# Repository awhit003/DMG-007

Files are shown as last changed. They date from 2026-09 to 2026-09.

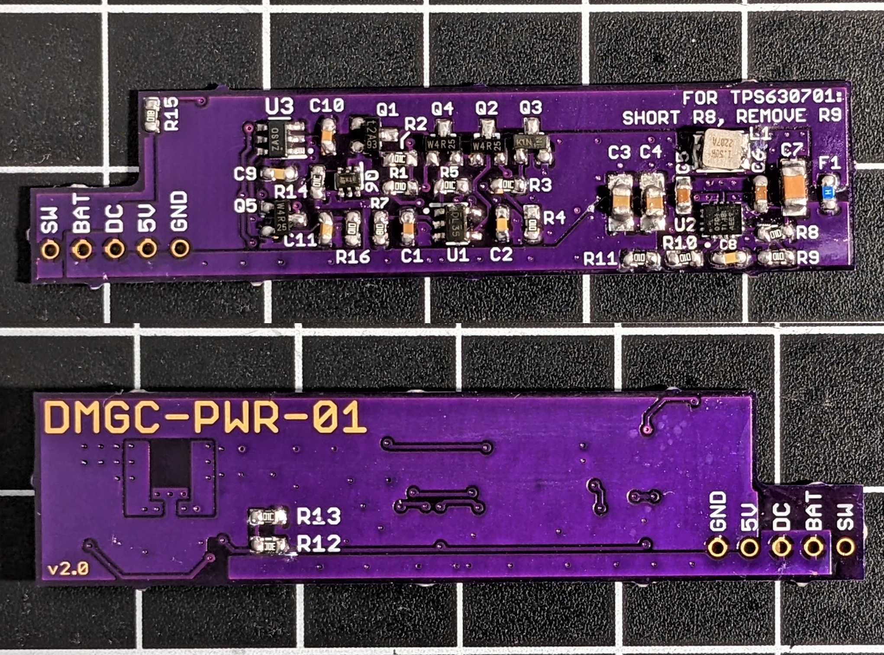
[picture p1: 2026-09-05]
hardware/boards/03-dmgc-pwr-01/DMGC-PWR-01_2-0_ASSEMBLED.png

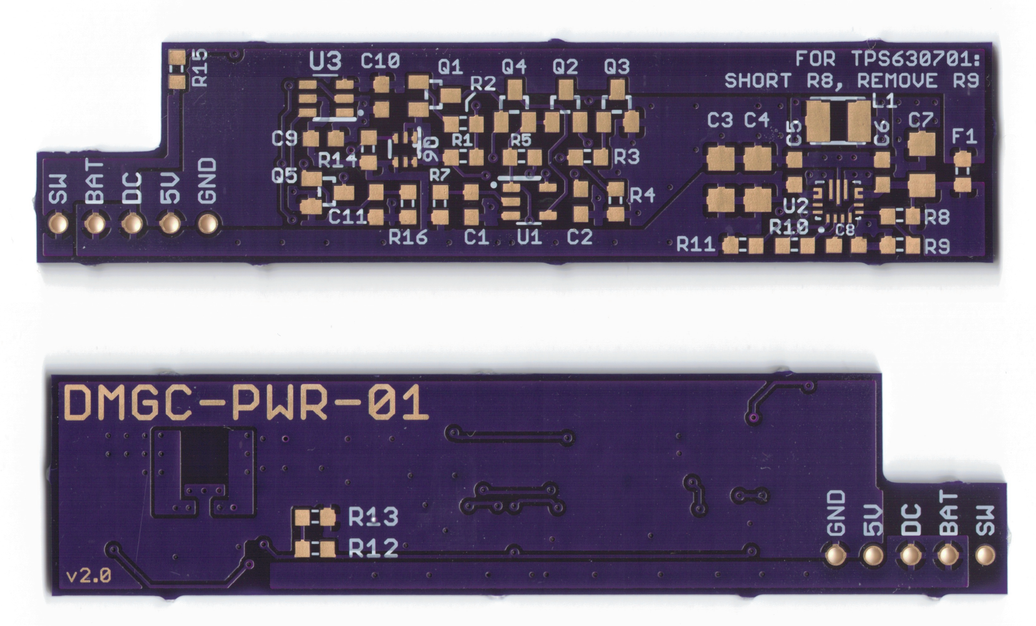
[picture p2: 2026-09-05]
hardware/boards/03-dmgc-pwr-01/DMGC-PWR-01_2-0.png

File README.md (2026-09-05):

# DMG-007

**DMG-007** is a modern hardware integration and re-engineering project for the original Nintendo Game Boy (DMG) form factor. 

The core philosophy of DMG-007 is **zero donor DMG-001 parts**: the console is built entirely from newly fabricated PCBs, modern off-the-shelf components, and automated surface-mount assembly. The **sole donor component** in the entire build is a salvaged **SGB-CPU** from a Japanese Super Famicom / Super Game Boy cartridge.

The designs and documentation are fabrication-agnostic and universally compatible with major PCB fabrication services including **OSH Park**, **PCBWay**, and **JLCPCB**.

---

## 🎯 Design Parameters & Architecture

1. **Zero DMG-001 Consoles Sacrificed:**
   - No original DMG-001 motherboards, power boards, audio boards, or screens are consumed.
   - The primary processor is an **SGB-CPU** (harvested from readily available Japanese Super Game Boy cartridges).
   - VRAM, work RAM, crystal oscillators, and audio amplification all use modern, commercially available replacement silicon and passives.

2. **Automated Surface-Mount (SMT) Assembly:**
   - Boards are designed with standard surface-mount packages (0805/0603 passives, standard IC packages) to allow automated pick-and-place assembly.
   - SGB-CPU (U1) and through-hole mechanical connectors (cartridge slot, headphone jack, battery contacts) are populated post-assembly.
   - Vendor-specific manufacturing instructions (e.g., JLCPCB/JLCONE tooling and LCSC part mappings) are maintained in dedicated vendor documentation.

3. **High-Performance Reflective Display (Sharp RLCD):**
   - Incorporates a modern ultra-fast 1-bit Reflective LCD panel (Sharp Memory LCD / RLCD `LS032B7DD02`, 3.2", 336×536).
   - Preserves the authentic, glare-free, outdoor-readable aesthetic of the original monochrome DMG without backlights or motion smear.
   - Driven by an on-board Raspberry Pi RP2040 utilizing clean-room PIO capture and 2×2 Bayer dithering.

4. **"God View" VRAM Bus Snooping (256×256 Viewport Expansion):**
   - The Sharp driver board includes a dedicated **24-pin 0.5mm FPC expansion port (`J4_VRAM_SNOOP`)**.
   - Snoops the Game Boy VRAM bus (`A0–A12`, `D0–D7`, `/WR`) via an optional parasitic flex cable.
   - Enables hardware capture of the entire internal 256×256 pixel background tilemap in real time, unlocking full-canvas wide-angle rendering beyond the clipped 160×144 PPU viewport.

5. **Clean Power Delivery:**
   - Dedicated high-efficiency synchronous buck-boost regulation (`DMGC-PWR-01`) delivering a rock-solid, isolated 5V rail capable of supporting the RLCD controller and modern audio amplifier across varying battery discharge curves.

---

## 🧩 Integrated Hardware Components & Attribution

This project brings together foundational designs created by talented open-source hardware developers across the retro-modding community:

| Module | Source Design | Original Author | Upstream License | Function in DMG-007 |
| :--- | :--- | :--- | :--- | :--- |
| **Motherboard** | [Super-DMG-01](https://github.com/kamicane/Super-DMG-01) | **kamicane** (Valerio Proietti) | CC BY-SA 4.0 | Main system logic board engineered to host the SGB-CPU, modern RAM, and USB-C power integration. |
| **Audio Board** | [Super DMG JACK](https://github.com/kamicane/Super-DMG-01) | **kamicane** (Valerio Proietti) | CC BY-SA 4.0 | Independent headphone and speaker audio board utilizing a PAM8302 mono Class-D amplifier. |
| **Power Supply** | [DMGC-PWR-01](https://github.com/MouseBiteLabs/Game-Boy-DMG-Color) | **MouseBiteLabs** (Bucket Mouse) | CC BY-SA 4.0 | High-efficiency buck-boost regulator board (TPS630702 based) with undervoltage latching. |
| **Display Subsystem**| Clean-Room Sharp RLCD Driver | DMG-007 Project | CC BY-SA 4.0 | RP2040 controller driving Sharp LS032B7DD02 with PIO capture, 2×2 Bayer dither, and 24-pin VRAM snooping bus. |

For detailed license terms and derivative compliance requirements, see [NOTICE.md](NOTICE.md) and [LICENSE](LICENSE).

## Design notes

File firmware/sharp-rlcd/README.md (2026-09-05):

# DMG-007 Sharp RLCD Driver Firmware

Clean-room open-source firmware for Raspberry Pi RP2040 driving the Sharp Memory LCD (LS032B7DD02) from Nintendo Game Boy DMG LCD signals.

## Architecture

* **PIO 0**: Samples Game Boy LCD `DATA0` and `DATA1` on `CL2` (pixel clock) falling edge.
  * Synchronized by `CL1` (horizontal line latch) and `VSYNC` (frame start).
* **DMA**: Transports line buffers to Core 1 without CPU intervention.
* **Core 1**: Converts 2-bit grayscale pixels (160x144) to 1-bit black & white (320x288) via 2x2 Bayer dithering matrix.
* **Core 0**: Handles USB interface, COM inversion periodic toggle (required for Sharp Memory LCD health), and system status.
* **SPI Controller**: Streams the 320x288 1-bit frame to the Sharp panel over high-speed serial bus at 60 Hz.

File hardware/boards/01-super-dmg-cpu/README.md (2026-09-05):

# Super DMG CPU

Super DMG CPU works with both IPS and DOT MATRIX LCD boards.

top bottom

## Credits

The schematic is largely based on [the work done by bit 9](https://imgur.com/a/X5qKI).

I used [Gekkio KiCAD libs](https://github.com/Gekkio/gekkio-kicad-libs) for a few symbols (cpu, ram, cart connector, link port). The specialized footprints were traced by me using fusion 360, using these [scans by bit 9](https://chipmusic.org/forums/topic/13608/dmg-main-board-schematic-circuit-arduinoboy/) as a reference.

## Warning

v1.8 and below have an error with the Link Port, where the footprint was flipped (sigh). If you have a v1.8 or below please don't use the link port, as it might damage the other Game Boy! This was fixed in later versions.

## Features

### Compatibility

Super DMG CPU can be built using new components, except for the CPU, power switch and link connector. It is also possible to use some components harvested from a DMG.

### USB Type-C

The round power connector is replaced with an USB Type-C port. The port is only connected to a pad on the motherboard, you need to add your own battery charger and/or power regulator if you want to make use of it. This port is optional.

### Power distribution IC

A power distribution IC takes the system load away from the power switch, so the game boy remains fully operational even if the switch is not in an optimal condition. This circuit can be bypassed with a jumper.

### Internal ProSound

The headphone output does not pass through the amplifier, only the volume potentiometer.

## BOM

| Designator | Package | Qty | Value / Description | Source |
|---|---|-----|---|---|
| U1 | QFP-80 14x20 p0.8 | 1 | CPU | DMG, SGB
| U2 | SOP-28 17.5x8.4 p1.27 | 1 | VRAM | DMG, SGB, [LCSC](https://lcsc.com/product-detail/C1351073.html)
| U3 | SOP-28 17.5x8.4 p1.27 | 1 | RAM | DMG, SGB, [LCSC](https://lcsc.com/product-detail/C1351073.html)
| U4 | SSOP-18 6x7.4 p0.8 | 1 | Audio Amplifier | DMG
| EXT1 | | 1 | Link Connector | DMG
| DA1, DA2, DA3, DA4 | SOT-23-3 | 4 | BAV99-7-F | [LCSC](https://www.lcsc.com/product-detail/C106919.html)
| C1, C23 | 3528 | 2 | 100µf tantalum | [LCSC](https://lcsc.com/product-detail/C122271.html)
| SW1 | | 1 | Power Switch | DMG
| U5 | SOT-23-5 | 1 | Power Distribution | [LCSC](https://lcsc.com/product-detail/C517266.html)
| D2 | SOD-123 | 1 | 1N414 | [LCSC](https://lcsc.com/product-detail/C83528.html)
| X1 | HC-49S | 1 | 4.194304 MHz | DMG, [LCSC (TH)](https://lcsc.com/product-detail/C718646.html), [LCSC (SMD)](https://lcsc.com/product-detail/C2149317.html)
| USB1 | USB_C_16p | 1 | Charge Connector | [LCSC](https://lcsc.com/product-detail/C2931472.html)
| VR1 | | 1 | Volume Pot | DMG, [AliExpress](https://www.aliexpress.com/item/32840044311.html)
| CN1 | 1.25 x 21 SMD | 1 | LCD Board Connector | DMG, [AliExpress](https://www.aliexpress.com/item/1005005484837763.html)
| CN2 |  | 1 | Cart Connector | DMG, [AliExpress](https://www.aliexpress.com/item/1005002719771295.html)
| CN3 | | 1 | AA Battery Contacts | DMG, [AliExpress](https://www.aliexpress.com/item/32801068366.html)
| CN4 | 1.25 TH | 1 | Lipo Battery Connector | [LCSC](https://www.lcsc.com/product-detail/C722595.html)
| C3, C4 | 0805 | 2 | 1µF |
| C5, C6 | 0805 | 2 | 10µF |
| C7, C8, C9 | 0805 | 3 | 47nF |
| C10, C24, C25 | 0805 | 3 | 100nF |
| C12, C13, C14 | 0805 | 3 | 10nF |
| C16, C17, C18, C19 | 0805| 4 | 100pF |
| C21, C22 | 0805 | 2 | 27pF |
| R1, R2, R3, R4 | 0805 | 4 | 220Ω|
| R5, R6 | 0805 | 2 | 510Ω |
| R7 | 0805 | 1 | 180kΩ |
| R8 | 0805 | 1 | 1MΩ |
| R9 | 0805 | 1 | 10kΩ |
| R10, R11 | 0805 | 2 | 5.1kΩ |

## Assembly

- Solder all SMD components on the front side
- If using a power board with integrated power distribution close ```J5``` and do not install ```U5```, ```C24```, ```C25```, ```R9```
- If using an external amplifier, such as [Super DMG JACK](../super-dmg-jack) do not install ```U4```, ```C5-C9```, ```C23```
- If you do not need link functionality you can omit ```EXT1```, ```DA1-DA4```, ```R1-R4```, ```C16-C19```, ```D2```
- Solder the through hole components and the LCD board connector
- (Optional) solder the usb connector and cut an opening for the usb port in the front shell using the provided [rudimentary jig](../3d_models/dmg_usbc_jig.stl)
- The original DC jack hole can be covered with this simple [3d printed plug](../3d_models/dmg_dc_plug.stl)

## Notes

If using an original LCD board you need an original *DMG DC CONV* voltage regulator, as acceptable modern replacements that also include the -18v rail *do not exist yet*.

This pcb cannot be easily biverted yet.

## Ordering

[pcbway](https://www.pcbway.com/QuickOrderOnline.aspx?projectid=13266&issmt=0)
[pcbway](https://pcbway.com/g/Gw03Yt)

Make sure you order with 1.0mm thickness.

## License

This work is licensed under the [Creative Commons Attribution-ShareAlike 4.0 International License.](http://creativecommons.org/licenses/by-sa/4.0/)

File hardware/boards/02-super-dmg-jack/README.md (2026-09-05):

# Super DMG JACK

Super DMG JACK is a replacement headphone/audio PCB for the original Game Boy. It can be used on a stock DMG or the Super DMG-01.

It uses a PAM8302 mono amplifier to power the speaker when no headphones are present, but it can also be built as a headphone jack replacement using the amplifier on the CPU board.

The amplifier schematic is based on [Adafruit's pam8302 amplifier PCB](https://github.com/adafruit/Adafruit-PAM8302-Mono-Amplifier-PCB).

The headphone output needs to be unamplified, and grabbed _after_ the DMG volume potentiometer.

sdmg jack top sdmg jack bottom

sdmg jack sdmg jack full

## BOM

| Designator | Package | Qty | Value / Description | Source |
|---|---|-----|---|---|
| CN1 | PJ-3043-B | 1 | Headphone connector | [LCSC](https://lcsc.com/product-detail/C2682182.html) |
| CN2 | 1.25 TH | 1 | CPU PCB Connector | [LCSC](https://lcsc.com/product-detail/C722595.html) |
| CN3 | 1.25 TH | 1 | Speaker Connector | [LCSC](https://lcsc.com/product-detail/C722604.html) |
| U1 | SOP-8 | 1 | PAM8302 | [LCSC](https://lcsc.com/product-detail/C112137.html) |
| U2 | SOT-23-5 | 1 | SN74AHC1G14 | [LCSC](https://lcsc.com/product-detail/C7469.html) |
| VR1 | Bourns TC33X-2-103E | 1 | 10kΩ SMD | [LCSC](https://lcsc.com/product-detail/C719176.html) |
| FB1, FB2 | 0805 | 2 | Ferrite Bead ||
| C1, C2, C5 | 0805 | 3 | 1µf ||
| C3, C4 | 0805 | 3 | 220pf ||
| R1, R2 | 0805 | 2 | 220Ω ||
| R3, R4 | 0805 | 2 | 100Ω ||
| R5 | 0805 | 1 | 10kΩ ||

I got premade wires from [AliExpress](https://www.aliexpress.com/item/1005002353691025.html) (1.25mm 2p and 5p), but you can also just use 28/30 awg without connectors.

I use "WSC" 8Ω 2W speakers from AliExpress.

## DMG Pinout

dmg-pinout

## Full Installation

Important: do not solder ```U2``` and/or do not wire the (E)nable signal. The speaker must be connected to this board.

- Solder the SMD components
- Solder the through hole components
- On the stock DMG solder the L/R signals to the volume potentiometer (** after pot), on Super DMG-01 solder to the bottom pads directly
- Get power from the 5v rail on the CPU board
- Adjust the trimpot

### Trimpot notes

Adjust the trimpot to reduce the power draw and max volume of the amplifier. Boot the DMG at minimum volume, and slowly turn it up, while also adjusting the trimpot. The Game Boy will shut down if you're drawing too much power.
Do the final trimpot adjustment once the DMG volume is at its maximum value.

The final maximum volume will depend on the batteries and the voltage regulator you're using.

## Jack-only Installation

The jack-only installation is meant to be used with the on-board DMG amplifier, however you still need to solder an extra wire for power as the ENABLE signal needs to be inverted.

Important: solder only ```U2```, ```R5```, the headphone jack and the CPU PCB connector. The speaker must be kept in the LCD board.

- Solder the SMD components
- Solder the through hole components
- On the stock DMG solder the L/R signals to the volume potentiometer (** after pot), on Super DMG-01 solder to the bottom pads directly
- Get power from 5V (Super DMG CPU) or SW (stock DMG) on the CPU board

## Notes

3d print the [jack spacer](../3d_models/super_dmg_jack_spacer.stl) for correct alignment.

## Ordering

[pcbway](https://www.pcbway.com/QuickOrderOnline.aspx?projectid=13350&issmt=0)
[pcbway](https://pcbway.com/g/Gw03Yt)

Make sure you order in 1.0mm thickness.

## License

This work is licensed under the [Creative Commons Attribution-ShareAlike 4.0 International License.](http://creativecommons.org/licenses/by-sa/4.0/)

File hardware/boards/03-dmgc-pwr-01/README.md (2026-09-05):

# DMGC-PWR-01

DMGC-PWR-01_2-0_black
DMGC-PWR-01_2-0_ASSEMBLED_black

*Note: This image shows v2.0. There is minimal difference between this and v2.3.*

The PWR board has gone through a few iterations. Because the system will run with 4x AA batteries or the DC jack input, the range of input voltages is relatively wide - anywhere between ~4 V up to ~8 V, plus margin. The output voltage must be maintained at 5 V. The logical choice would be a buck-boost converter. Thus, the DMGC-PWR-01 utilizes the TPS630702 (or TPS63070 or TPS630701) – a buck-boost converter with only a few external parts required for operation, that accepts anywhere between 2 V and 16 V to produce a 5 V output.

This board is likely the most complex part of the build. I spent a lot of time tuning the circuit to produce the exact results I wanted with ample protection downstream of the converters.

For a technical explanation of the CPU board, please view the README in the Technical folder.

## Board Characteristics
The zipped folder contains all the gerber files for this board.
-	Layers: 2
-	Thickness: 1.2 mm or smaller
-	Surface Finish: ENIG or HASL

*HASL is acceptable, but might introduce a bit of difficulty soldering the QFN chip owing to the possibly uneven surface compared to an ENIG finish.*

<a href="https://www.etsy.com/listing/1317694018/game-boy-dmgc-pwr-board">**I sell this board on Etsy, so you don't have to buy multiples from board fabricators.**</a>

You can alternatively use the zipped folder at any board fabricator you like. You may also buy the board from PCBWay using this link (disclosure: I receive 10% of the sale value to go towards future PCB orders):

<a href="https://www.pcbway.com/project/shareproject/Game_Boy_DMG_Color_DMGC_PWR_01_f8f2e84a.html">PCB from PCBWay</a>

## Configuring for Different TPS chips on U2

For TPS63070 or TPS630702, R8 needs to be 523k and R9 needs to be 100k, as indicated in the BOM.

For TPS630701, you need to short R8 with a solder bridge/wire or a zero ohm resistor, and remove R9 completely.

**It is critical you configure the board correctly, otherwise you may damage your system.**

## Using in an Original DMG (UNTESTED!)

This board can (probably) be used as a replacement to the original DMG power board, provided you are using an IPS screen that only requires a 5 V output. This board will not supply voltages for the LCD, so it cannot be used in an unmodded DMG.



Follow the silkscreen on the back of the board to connect wires to the DMG motherboard, as shown below (image from Gekkio's Game Boy Hardware Database: https://gbhwdb.gekkio.fi/consoles/dmg/). The red wire on the main DMG CPU board indicates pin 1. The blue box on the back of the DMG CPU board indicates the connection for the BAT hole.



IF you happen to test this (at your own risk!) let me know your results.

## Bill of Materials

Here, I have provided links to components I used personally (or suitable replacements). This BOM is also included in Excel format in the root folder.

| Reference Designators | Qty | Value/Part Number | Package | Description | Comment | Source |
| --- | --- | --- | --- | --- | --- | --- |
| C1, C5, C6 | 3 | 10uF | 0603 | Capacitor (MLCC) | Should be X5R (or better), at least 16V | [https://www.mouser.com/ProductDetail/Murata-Electronics/GRM188R61E106KA73J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](https://www.mouser.com/ProductDetail/Murata-Electronics/GRM188R61E106KA73J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) |
| C3, C4 | 2 | 22uF | 1206 | Capacitor (MLCC) | Should be X5R (or better), at least 16V | [https://www.mouser.com/ProductDetail/Samsung-Electro-Mechanics/CL31A226KAHNNNE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](https://www.mouser.com/ProductDetail/Samsung-Electro-Mechanics/CL31A226KAHNNNE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) |
| C7 | 1 | 47uF | 1206 | Capacitor (MLCC) | Should be X5R (or better), at least 16V | [https://www.mouser.com/ProductDetail/Murata-Electronics/GRM31CR61C476ME44K?qs=QzBtWTOodeVeYV6UhCOqow%3D%3D](https://www.mouser.com/ProductDetail/Murata-Electronics/GRM31CR61C476ME44K?qs=QzBtWTOodeVeYV6UhCOqow%3D%3D) |
| C8, C9, C11 | 3 | 0.1uF | 0603 | Capacitor (MLCC) | | [https://www.mouser.com/ProductDetail/?qs=l5k%252BbMnNDknCtKnMv1oEgA%3D%3D](https://www.mouser.com/ProductDetail/?qs=l5k%252BbMnNDknCtKnMv1oEgA%3D%3D) |
| C10 | 1 | 0.01uF | 0603 | Capacitor (MLCC) | | [https://www.mouser.com/ProductDetail/KEMET/C0603C103J5RACTU?qs=BimOss5pjlFJEfKhlb7g1g%3D%3D](https://www.mouser.com/ProductDetail/KEMET/C0603C103J5RACTU?qs=BimOss5pjlFJEfKhlb7g1g%3D%3D) |
| F1 | 1 | 1A | 0603 | Fuse | | [https://www.mouser.com/ProductDetail/Vishay-Beyschlag/MFU0603FF01000P100?qs=oI046glRurtlP8n%252B3l7CPg%3D%3D](https://www.mouser.com/ProductDetail/Vishay-Beyschlag/MFU0603FF01000P100?qs=oI046glRurtlP8n%252B3l7CPg%3D%3D) |
| L1 | 1 | 1.5uH | 1212 | Inductor | Saturation current should be at least 2A | [https://www.mouser.com/ProductDetail/70-IHLP1212BZER1R5M1](https://www.mouser.com/ProductDetail/70-IHLP1212BZER1R5M1) |
| Q1 | 1 | MMBT3906 | SOT23 | PNP BJT | | [https://www.mouser.com/ProductDetail/Micro-Commercial-Components-MCC/MMBT3906HE3-TP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](https://www.mouser.com/ProductDetail/Micro-Commercial-Components-MCC/MMBT3906HE3-TP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) |
| Q2, Q4, Q5 | 3 | 2N7002 | SOT23 | N-channel MOSFET | | [https://www.mouser.com/ProductDetail/Nexperia/2N7002NXBKR?qs=%252B6g0mu59x7J2ddJstTJGkQ%3D%3D](https://www.mouser.com/ProductDetail/Nexperia/2N7002NXBKR?qs=%252B6g0mu59x7J2ddJstTJGkQ%3D%3D) |
| Q3 | 1 | MMBT3904 | SOT23 | NPN BJT | | [https://www.mouser.com/ProductDetail/Nexperia/MMBT3904VL?qs=cnAQGvEIVkKbCwIpHJoHxQ%3D%3D](https://www.mouser.com/ProductDetail/Nexperia/MMBT3904VL?qs=cnAQGvEIVkKbCwIpHJoHxQ%3D%3D) |
| Q6 | 1 | SI1443EDH | SOT363 | P-channel MOSFET | | [https://www.mouser.com/ProductDetail/Vishay-Semiconductors/SI1443EDH-T1-GE3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](https://www.mouser.com/ProductDetail/Vishay-Semiconductors/SI1443EDH-T1-GE3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) |
| R1, R4, R7, R9, R10, R11, R16 | 7 | 100k | 0603 | Resistor | R9 should have at least 1% tolerance | [https://www.mouser.com/ProductDetail/YAGEO/RC0603FR-07100KL?qs=e1ok2LiJcmaihem8Va5%2Fsw%3D%3D](https://www.mouser.com/ProductDetail/YAGEO/RC0603FR-07100KL?qs=e1ok2LiJcmaihem8Va5%2Fsw%3D%3D) |
| R2, R3, R5, R13, R14 | 5 | 10k | 0603 | Resistor | | [https://www.mouser.com/ProductDetail/YAGEO/RC0603FR-0710KL?qs=grNVn54RoB%252B3GtjbJj3wJQ%3D%3D](https://www.mouser.com/ProductDetail/YAGEO/RC0603FR-0710KL?qs=grNVn54RoB%252B3GtjbJj3wJQ%3D%3D) |
| R15 | 1 | 1k | 0603 | Resistor | | [https://www.mouser.com/ProductDetail/YAGEO/RC0603FR-071KL?qs=VU8sRB4EgwApHsk4rF%2F3zg%3D%3D](https://www.mouser.com/ProductDetail/YAGEO/RC0603FR-071KL?qs=VU8sRB4EgwApHsk4rF%2F3zg%3D%3D) |
| R8 | 1 | 523k | 0603 | Resistor | At least 1% tolerance. Not needed if using TPS630701 | [https://www.mouser.com/ProductDetail/YAGEO/RC0603FR-07523KL?qs=TkC2zyCLazpzUFWuXe7EHg%3D%3D](https://www.mouser.com/ProductDetail/YAGEO/RC0603FR-07523KL?qs=TkC2zyCLazpzUFWuXe7EHg%3D%3D) |
| R12 | 1 | 20k | 0603 | Resistor | | [https://www.mouser.com/ProductDetail/YAGEO/RC0603FR-0720KL?qs=VU8sRB4EgwCsxfrjtEIKPQ%3D%3D](https://www.mouser.com/ProductDetail/YAGEO/RC0603FR-0720KL?qs=VU8sRB4EgwCsxfrjtEIKPQ%3D%3D) |
| U1 | 1 | TPS3840DL35 | SOT23-5 | Supervisory IC | Could feasibly use TPS3840DL32 if 35 is out of stock | [https://www.mouser.com/ProductDetail/Texas-Instruments/TPS3840DL35DBVR?qs=7MVldsJ5UawbjRj7dP73rA%3D%3D](https://www.mouser.com/ProductDetail/Texas-Instruments/TPS3840DL35DBVR?qs=7MVldsJ5UawbjRj7dP73rA%3D%3D) |
| U2 | 1 | TPS63070, TPS630701, TPS630702 | 15-VQFN-HR | Buck-boost converter | Might be difficult to find. TPS630702 preferred, but all will work. Check https://octopart.com/search?q=tps63070&currency=USD&specs=0 | [https://www.mouser.com/ProductDetail/Texas-Instruments/TPS630702RNMT?qs=vLWxofP3U2wR9GhA3fXurw%3D%3D](https://www.mouser.com/ProductDetail/Texas-Instruments/TPS630702RNMT?qs=vLWxofP3U2wR9GhA3fXurw%3D%3D) |
| U3 | 1 | TPS3702CX50 | SOT23-6 | Supervisory IC | Optional IF you fully test the power board and confirm proper 5V operation | [https://www.mouser.com/ProductDetail/595-TPS3702CX50DDCR](https://www.mouser.com/ProductDetail/595-TPS3702CX50DDCR) |

## Revision History

### v2.3
- Moved some components
- Removed C2 (not needed on previous revisions either)
- Fixed DMG connection silkscreen
- Changed RC time constant for undervoltage detection
- Added test points across the board

### v2.2
- Added F1 back
- Added DMG connections notation on silkscreen

### v2.1
- Moved R12/R13 to front of the board
- Removed F1

### v2.0 (for sale)
- Release version

## License
<br />This work is licensed under a <a rel="license" href="http://creativecommons.org/licenses/by-sa/4.0/">Creative Commons Attribution-ShareAlike 4.0 International License</a>. You are able to copy and redistribute the material in any medium or format, as well as remix, transform, or build upon the material for any purpose (even commercial) - but you **must** give appropriate credit, provide a link to the license, and indicate if any changes were made.

©MouseBiteLabs 2022

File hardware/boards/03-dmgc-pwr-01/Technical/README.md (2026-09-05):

# Technical Design Document

This write-up serves as a technical explainer for the DMGC-PWR-01. This board is the powerhouse of the cell.

## Schematic and CPU Board Interfacing

There are five wires that connect to the CPU board power supply circuitry. Pin 1 is the GND reference and pin 2 is the 5 V output from the PWR board. Pin 4, VCC, is the input voltage, which is always powered from the CPU board. SW is the output of half the power switch on the CPU board - connected to VCC when on, floating when off (ultimately tied to GND through R16 on the PWR board). On the CPU board, pin 3 is connected to the DC jack output, but on this board I connect this to VCC as well, so that either batteries or the DC jack will power this board. A different revision might utilize the DC jack for something else, such as charging a LiPo battery, which is why I left these pins separate.



The battery voltage, VCC, is applied to the buck-boost input voltage pin, without routing through the power switch on the CPU. Instead, the power switch controls the buck-boost converter’s enable pin through a load switch circuit.

## Buck-Boost Converter (U2)

U2 can be TPS63070, TPS630701, or TPS630702. TPS630701 is a fixed 5 V buck-boost, while the other two have adjustable output via a voltage divider. The only difference between TPS63070 and TPS630702 is that the latter has an output discharge function - when the output is disabled, a low impedance (~200 Ω) is connected to the rail internally to quickly discharge the output capacitors. If you have a choice, I would recommend using the TPS630702 over the other two, and the TPS630701 over the TPS63070 just because it's a bit more convenient (and foolproof) to use the fixed output version of the chip. But any three of them will work perfectly fine.

The bottom third of the schematic is the entire buck-boost stage. I followed the TPS63070 datasheet for choosing values of the input and output capacitance, the inductor, and the feedback resistors. R8 and R9 set up a voltage divider for setting the output of the adjustable TPS630702 or TPS63070 – if the TPS630701 is used instead, which is the 5 V fixed output version, then R8 should be short circuited and R9 can be removed. **If you leave R8 and R9 at the values they are with the fixed 5 V chip, the output will shoot up to ~11V. I strongly recommend testing this power supply board separately from the rest of the system to ensure the 5 V output is correct and steady, without frying anything else downstream.**

The buck-boost chip is activated when the EN pin is higher than 800 mV (there is an internal ~70 microsecond delay before activation after this voltage is reached). This pin is controlled by the PSU_EN net, which is influenced by two chips – U3 (overvoltage protection) and U1 (undervoltage detection). If no errors are detected in the power supply, then PSU_EN will pull up to VCC_LATCH and activate U2. If either an overvoltage on the 5 V line or an undervoltage on the battery supply is detected, the PSU_EN net is pulled to GND and latched off until the power switch is cycled. R5, R12, and R13 set up voltage dividers that ensure if the EN pin passes 800 mV, the gate-source voltage on Q2 will be at least 2.4 V, meaning the latching circuit will be set up before the 5 V supply is generated (VGSth of Q2 is ~2.1 V, max). R13 also ensures the EN pin is pulled to GND when the power switch is turned off. Detailed operation on the PSU_EN net can be found below. 

F1 is a 1 A fuse on the 5 V output, which in hindsight is probably overkill, since the CPU board has protections that will likely always trip first (the 1 A PTC specifically). When testing the PWR board, I shorted the 5 V supply to GND to see if the fuse would pop, and the PTC opened up first every time I tried. But, I have plenty of 1 A fuses lying around, so there’s little reason not to include it just in case, since the TPS63070 chips can output up to 3.6 A. A fuse could prevent a feed-the-fault type of error, however rare that scenario likely is.

## Overvoltage Protection (U3)

Onto the protection circuitry - let's get the easy one out of the way first. U3 is a TPS3702 IC. This chip monitors the 5 V output on the SENSE pin. If it’s above a certain value, the output on the OV pin will be pulled low. Otherwise, OV is left floating (it's an open-drain output), so it doesn’t affect the output of the PSU_EN net during normal operation.

The specific part I have chosen is the TPS3702CX50. With the SET pin tied to GND, this sets the overvoltage threshold to 5.45 V. If the supply ever passes this point, then the overvoltage pin will pull PSU_EN low, and the latching circuit will keep it off until the power switch is cycled.

The overvoltage protection is likely overkill as well, as long as the buck-boost circuit is set up correctly and soldered properly. Since the adjustable TPS63070 chips measure the feedback through the FB pin, it will maintain the 5 V as long as no solder bridges or poor solder connections cause the wrong voltage to be measured by the chip (assuming the rest of the circuit is set up properly). You can omit U3, C9, and C10 to remove the overvoltage detection without impacting the operation of rest of the circuit.

## Undervoltage Detection (U1)

U1 is a TPS3840 chip which monitors the voltage on the batteries via the VDD pin. When it detects the voltage has gone below a specific threshold, the /RESET pin is pulled low. This output is open-drain, so it does not affect the PSU_EN net while not in an error state.

The specific part I chose was the TPS3840DL35. The DL indicates the /RESET is an active-low open-drain output. (PL would indicate active-low push-pull output, PH would indicate active-high push-pull, both of which aren’t suitable for my specific application). The threshold voltage is determined by the last two numbers, which for my selection is 35 for 3.5 V. I chose this threshold based on the guidelines from <a href="https://data.energizer.com/pdfs/nickelmetalhydride_appman.pdf">this application note from Energizer.</a> This documentation recommends using a voltage cutoff of ~75% of nominal voltage for a pack of NiMH AA batteries (what I will most commonly be using in my personal console). Nominal voltage of a NiMH AA battery is 1.2 V, so for four of them in series, the 75% level is 3.6 V. So the 3.5 V cutoff is close enough, and as a bonus, it's a part used on the CPU board already.

The VDD pin of U1 isn’t directly powered by the battery voltage. C1 and R7 on the battery voltage filter out any fast power supply transients. I found that during the start-up sequence, the loads on the 5 V supply will draw a considerable amount of current from the batteries, causing their voltage to dip about a volt max (this is normal, and the PTC on the CPU board does not drop the supply more than a few tens of millivolts). Furthermore, loud audio can introduce kHz range ripple on the battery voltage when their charge is low, so the low pass filter will smooth that out. It's not important for undervoltage lockout to occur immediately after the 3.5 V threhold is passed during a transient event, so this doesn't negatively impact performance or protection while the console is being used. Also, the current draw of the TPS3840 is less than a microamp, so the voltage drop across R7 is negligible and it also won't have any perceptible impact to battery life despite always being connected to the batteries.

The CT pin on this chip introduces a delayed start function. Adding a 1 uF capacitor to this pin will cause the /RESET output to be held low for approximately 620 milliseconds no matter what the supply voltage is. This is really only useful in the event you put the batteries in while the power switch is already on, because the delay only applies the first time power is applied to the chip. The wait period lets all the input capacitors charge up sufficiently and allows enough time for the input undervoltage latch to be set up before trying to generate the 5 V supply.

You might be asking - why am I including external input undervoltage detection on this board? Can't you just put a voltage divider on the enable pin of U2? Well...

## Latching Circuit

The original design of the PWR board had a funny problem, and didn't include the undervoltage lockout chip or latching circuitry. When the buck-boost enable pin was pulled low to disable the output once the batteries discharged enough, everything would turn off and thus remove the load from the batteries. When the current draw out of the batteries suddenly dropped to almost nothing, the battery voltage would rise back up, as expected. Unfortunately, this voltage would soon re-enable the buck-boost chip, starting up the 5 V supply. But... that would increase the load on the batteries, the voltage would drop below the enable pin threshold, and the system would shut off again. And that cycle would repeat. A bootloop! Not the graceful death the original Game Boy experienced when the batteries ran out of juice.

So in order to fix this, I introduced the undervoltage detection chip along with a latching circuit, so that as soon as the batteries died the *first* time, the system would keep itself shut off until the power switch was cycled. I found this strategy in <a href="https://www.ti.com/lit/an/snva836a/snva836a.pdf">this very helpful application note from Texas Instruments</a>. (You know, Texas Instruments should have sponsored this project, because I sure do use a lot of their parts)

The latching circuit consists of Q1 through Q4 and R1 through R4. You can read the application note for the full series of events, but basically turning on Q2 with a sufficient gate-source voltage sets up the latch. The next time the gate of Q2 (the PSU_EN net) is pulled to GND by the /RESET pin, Q4 is turned on to conduct and the /MR pin (master reset) is also pulled low. On the TPS3840, whenever /MR is low, /RESET will also automatically be pulled low no matter if VCC is above or below the undervoltage trip point. So even if the voltage rises back up above the trip limit, /RESET will keep Q4 conducting, which keeps /MR low as well. So the only way to reset the whole thing is to turn the power switch off and reset the latch.

## Load Switch

VCC is applied to the latching circuit through a load switch circuit, rather than the power switch directly. The power switch, which is connected to the SW net, controls the gate-source voltage of Q5, an N-channel FET. R15 and C11 set up an RC delay for switch debouncing, and R16 is a pull-down resistor for when the power switch is turned off. R14 is a pull-up resistor that keeps Q6, a P-channel FET, off whenever Q5 is off. When the power switch is turned on, Q5 conducts and pulls the gate of Q6 to GND. This allows the battery voltage VCC to turn on the latching circuit. Furthermore, if PSU_EN is not being pulled to GND by the supervisory ICs (if the battery voltage is higher than 3.5 V), then the enable pin of the buck-boost will pass the 800 mV threshold needed to turn on the 5 V supply (after a built-in 70 microsecond delay).

The benefit to using a load switch instead of the power switch directly is the contact resistance of the 30+ year old power switches is no longer a factor in operation. One common issue in old Game Boys is a voltage drop across a dirty power switch, because the entire system current flows through the switch. Sometimes, if the switch is particularly oxidized or dirty, the entire Game Boy could fail to turn on. Instead of having to clean out a power switch, a non-trivial task (especially for a DMG), a dirty power switch will still be able to properly control Q5, as long as contact resistance isn't higher than like, 100 kΩ. (And in that case, increase R16 to like 1 MΩ, and you might be ok!)

## Resources
-	<a href="https://www.ti.com/lit/ds/symlink/tps63070.pdf?ts=1647052355945">TPS63070 datasheet</a>
-	<a href="https://www.ti.com/lit/ds/symlink/tps3840.pdf?ts=1656386735143">TPS3840 datasheet</a>
-	<a href="https://www.ti.com/lit/ds/symlink/tps3702.pdf?ts=1656335717520">TPS3702 datasheet</a>
-	<a href="https://www.ti.com/lit/an/snva836a/snva836a.pdf">Latching a Voltage Supervisor Application Note</a>
-	<a href="https://data.energizer.com/pdfs/nickelmetalhydride_appman.pdf">Nickel Metal Hydride (NiMH) Handbook and Application Manual</a>

## License
<br />This work is licensed under a <a rel="license" href="http://creativecommons.org/licenses/by-sa/4.0/">Creative Commons Attribution-ShareAlike 4.0 International License</a>. You are able to copy and redistribute the material in any medium or format, as well as remix, transform, or build upon the material for any purpose (even commercial) - but you **must** give appropriate credit, provide a link to the license, and indicate if any changes were made.

©MouseBiteLabs 2022

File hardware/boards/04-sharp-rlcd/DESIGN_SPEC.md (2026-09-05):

# Board 04: Sharp RLCD Driver Board Design Specification

## 1. System Architecture
* **Target Display:** Sharp LS032B7DD02 (3.2" 336x536 Reflective Memory LCD)
* **Controller:** Raspberry Pi RP2040 (QFN-56)
* **Firmware Framework:** Raspberry Pi Pico C/C++ SDK (using PIO state machines)
* **Assembly Target:** 100% Turnkey JLCPCB SMT Assembly (Single-side SMD)

---

## 2. Complete Parts List (JLCPCB LCSC Part Numbers)

### Active Silicon
| Designator | Value / Part | Footprint | LCSC Part # | Role |
| :--- | :--- | :--- | :--- | :--- |
| **U1** | RP2040 | QFN-56 (7x7mm, 0.4mm pitch) | `C2914104` | Dual-core Cortex-M0+ MCU with PIO |
| **U2** | W25Q16JVSSIQ | SOIC-8 (208mil / 3.9x4.9mm) | `C49987` | 16 Mbit (2 MB) QSPI NOR Flash |
| **U3** | XC6206P332MR | SOT-23-3 | `C5446` | High-PSRR 3.3V LDO Voltage Regulator |

### Passive Components
| Designators | Value | Package | LCSC Part # | Purpose |
| :--- | :--- | :--- | :--- | :--- |
| **X1** | 12.000 MHz | SMD-3225-4P | `C112250` | RP2040 System Clock |
| **C14, C15** | 15 pF | 0402 | `C1554` | Crystal Load Capacitors |
| **C1, C2, C3, C4, C5, C6, C7, C8, C9** | 100 nF (0.1 µF) | 0402 | `C1525` | Power rail decoupling (1 per VDD/IOVDD pin) |
| **C10, C11** | 1 µF | 0402 | `C52923` | LDO Input/Output & Core Decoupling |
| **C12, C13** | 10 µF | 0603 | `C19702` | Bulk filtering on 5V and 3.3V rails |
| **R1, R2** | 27 Ω | 0402 | `C25111` | USB D+/D- impedance matching |
| **R3, R4** | 5.1 kΩ | 0402 | `C25905` | USB-C CC1/CC2 pull-downs (forces 5V USB source) |
| **R5** | 1 kΩ | 0402 | `C11702` | Flash /CS BOOTSEL pull-up |
| **R6, R7** | 10 kΩ | 0402 | `C25744` | Reset / Display control pull-ups |

### Connectors & Controls
| Designator | Description | Footprint | LCSC Part # | Connection |
| :--- | :--- | :--- | :--- | :--- |
| **J1** | 10-Pin 0.5mm FPC | `FH34SRJ-10S-0.5SH` | `C324723` | Directly to Sharp LS032B7DD02 display |
| **J2** | 18-Pin 1.0mm FPC | `CON_5051101892_MOL` | `C262334` | From Game Boy button board (LCD signals) |
| **J3** | 16-Pin USB-C Receptacle | `TYPE-C-31-M-12` | `C165948` | UF2 firmware flashing & serial debugging |
| **SW1** | Tactile Switch | `SW_SPST_PTS645` | `C318884` | BOOTSEL Button (drag-and-drop programming) |

---

## 3. Pin Mapping & Netlist Configuration

### Sharp Display Interface (J1: 10-Pin FPC)
* **Pin 1 (SCLK):** Connects to RP2040 `GPIO 18` (`SPI0_SCK`)
* **Pin 2 (SI / MOSI):** Connects to RP2040 `GPIO 19` (`SPI0_TX`)
* **Pin 3 (SCS / Chip Select):** Connects to RP2040 `GPIO 17` (`SPI0_CSn`) - *Active HIGH*
* **Pin 4 (EXTMODE):** Connects to `GND` (enables software VCOM toggle mode)
* **Pin 5 (DISP):** Connects to RP2040 `GPIO 20` (pull-up to 3.3V, controls display on/off)
* **Pin 6 (VDDA):** Connects to `+3.3V`
* **Pin 7 (VDD):** Connects to `+3.3V`
* **Pin 8 (VSSA):** Connects to `GND`
* **Pin 9 (VSS):** Connects to `GND`
* **Pin 10 (VCOM):** Handled via bit 1 in SPI command packet

### Game Boy LCD Capture Bus (J2: 18-Pin FPC)
* **`DATA0`:** Connects to RP2040 `GPIO 0` (PIO Input pin 0)
* **`DATA1`:** Connects to RP2040 `GPIO 1` (PIO Input pin 1)
* **`CL2` (Dot Clock):** Connects to RP2040 `GPIO 2` (PIO Clock / Trigger)
* **`CL1` (Line Latch):** Connects to RP2040 `GPIO 3` (Interrupt / Line sync)
* **`VSYNC` (Frame Sync):** Connects to RP2040 `GPIO 4` (Interrupt / Frame sync)
* **`FR` (LCD Inversion):** Connects to RP2040 `GPIO 5`
* **`+5V` Power In:** Connects to input of 3.3V LDO (U3)
* **`GND`:** Connects to System Ground

---

## 4. "God View" 24-Pin VRAM Snooping Bus (`J4_VRAM_SNOOP`)

To enable passive parallel capture of the entire 256x256 background tilemap directly from the Game Boy's VRAM chip, a dedicated 24-pin 0.5mm FPC connector (`Hirose FH12-24S-0.5SH` or equivalent, LCSC `C262334` / standard FPC) is integrated.

### Pinout Mapping:
| Pin | Signal | Direction | Destination on RP2040 |
| :---: | :---: | :---: | :--- |
| **1-8** | `VRAM_D0` - `VRAM_D7` | Input | `GPIO 6` through `GPIO 13` (8-bit data bus) |
| **9-21** | `VRAM_A0` - `VRAM_A12` | Input | Multiplexed / Bus Address latch lines |
| **22** | `VRAM_/WR` | Input | PIO Write-Strobe Trigger |
| **23** | `+3.3V` / `VCC` | Power | Reference power |
| **24** | `GND` | Ground | Ground reference |

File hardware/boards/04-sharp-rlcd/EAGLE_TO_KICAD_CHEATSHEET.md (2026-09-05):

# Autodesk EAGLE to KiCad Migration Cheat Sheet

Coming from EAGLE to KiCad can feel disorienting because EAGLE relies on **modal commands** (click a tool icon first, then click the object), whereas KiCad is **modeless and hover-based** (hover cursor over the component and tap a keyboard shortcut).

---

## 🖱️ 1. Mouse Behavior Differences

| Action | Autodesk EAGLE | KiCad |
| :--- | :--- | :--- |
| **Pan Workspace** | Middle-click drag (or right-click hold) | **Middle-click drag** OR **Right-click drag** |
| **Zoom** | Scroll wheel | **Scroll wheel** (zooms directly toward cursor) |
| **Context Menu** | Right-click (cancels current command) | **Right-click** (opens contextual tool menu) |
| **Select / Drag** | Select tool -> Click part | Hover -> press **`M`** (Move) or **`D`** (Drag with traces) |
| **Cancel / Exit tool**| Click `Stop` button or `Esc` | Press **`Esc`** |

> **Pro-Tip:** In KiCad, you **do not need to click a component first** to move or rotate it. Simply float your mouse pointer over the part and hit the key.

---

## ⌨️ 2. Common Keyboard Shortcuts Comparison

| Operation | EAGLE Equivalent | KiCad Schematic (Eeschema) | KiCad PCB Editor (Pcbnew) |
| :--- | :--- | :--- | :--- |
| **Add Component / Part** | `ADD` command | **`A`** | **`A`** (Footprint) |
| **Add Wire / Route Trace**| `NET` / `ROUTE` | **`W`** (Wire) | **`X`** (Route Track) |
| **Move Component** | `MOVE` | **`M`** (Move free) | **`M`** (Move free) |
| **Drag with Connected Wires/Traces** | N/A (EAGLE snaps nets) | **`G`** (Drag connected) | **`D`** (Drag track segment) |
| **Rotate Part** | Right-click while moving | **`R`** (Rotates 90°) | **`R`** (Rotates 90°) |
| **Flip / Mirror Part** | `MIRROR` tool | **`Y`** (Mirror X) / **`X`** (Mirror Y) | **`F`** (Flip to opposite copper layer) |
| **Add Net Label** | `LABEL` / `NAME` | **`L`** (Add Net Label) | N/A (Netlist driven) |
| **Add Power / Ground** | `ADD` -> supply1/2 | **`P`** | N/A |
| **Add Via** | Spacebar / click via icon | N/A | **`V`** (while routing track) |
| **Switch Active Layer** | Top dropdown menu | N/A | **`Page Up`** (Top) / **`Page Down`** (Bottom) |
| **Delete Item** | `DELETE` tool | **`Delete`** or **`Backspace`** | **`Delete`** or **`Backspace`** |
| **Edit Properties / Value**| Right-click -> Properties | **`E`** | **`E`** |
| **Copy / Duplicate** | `COPY` tool | **`Ctrl + D`** (Duplicate) | **`Ctrl + D`** |
| **Measure Distance** | `INFO` / Grid count | **`Shift + M`** | **`Shift + M`** |
| **Fill / Recalculate Copper Pour** | `RATSNEST` | N/A | **`B`** (Instant copper refour) |
| **Switch Copper Pour Display** | Layer visibility | N/A | Left toolbar icons (Show/Hide Zones) |

---

## 🚀 3. Mental Shifts That Will Save Your Sanity

1. **The "Ratsnest" Button:**
   - In EAGLE, you hit `RATSNEST` to calculate ground polygons and see remaining airwires.
   - In KiCad, just press **`B`** at any time. It instantly repours all copper ground zones and recalculates DRC clearances.

2. **Routing Traces (Push & Shove):**
   - EAGLE's default router is often frustrating with obstacle avoidance.
   - KiCad has a built-in **Interactive Push & Shove Router**: when you hit **`X`** and route a trace, it automatically and dynamically pushes existing traces and vias out of the way without creating DRC violations.

3. **Updating PCB from Schematic:**
   - In EAGLE, schematic and board are locked via "Back-Annotation" (closing one breaks synchronization).
   - In KiCad, they are decoupled: edit your schematic at will, then press **`F8`** (or `Tools` -> `Update PCB from Schematic`). KiCad pushes all new footprints, net changes, and deleted components straight into the PCB editor.

4. **Footprint Assignment:**
   - In EAGLE, the symbol and footprint are tied together in the library (`DEV`).
   - In KiCad, symbols and footprints can be paired flexibly. Press **`Tools` -> `Assign Footprints`** to review or change packages in bulk.

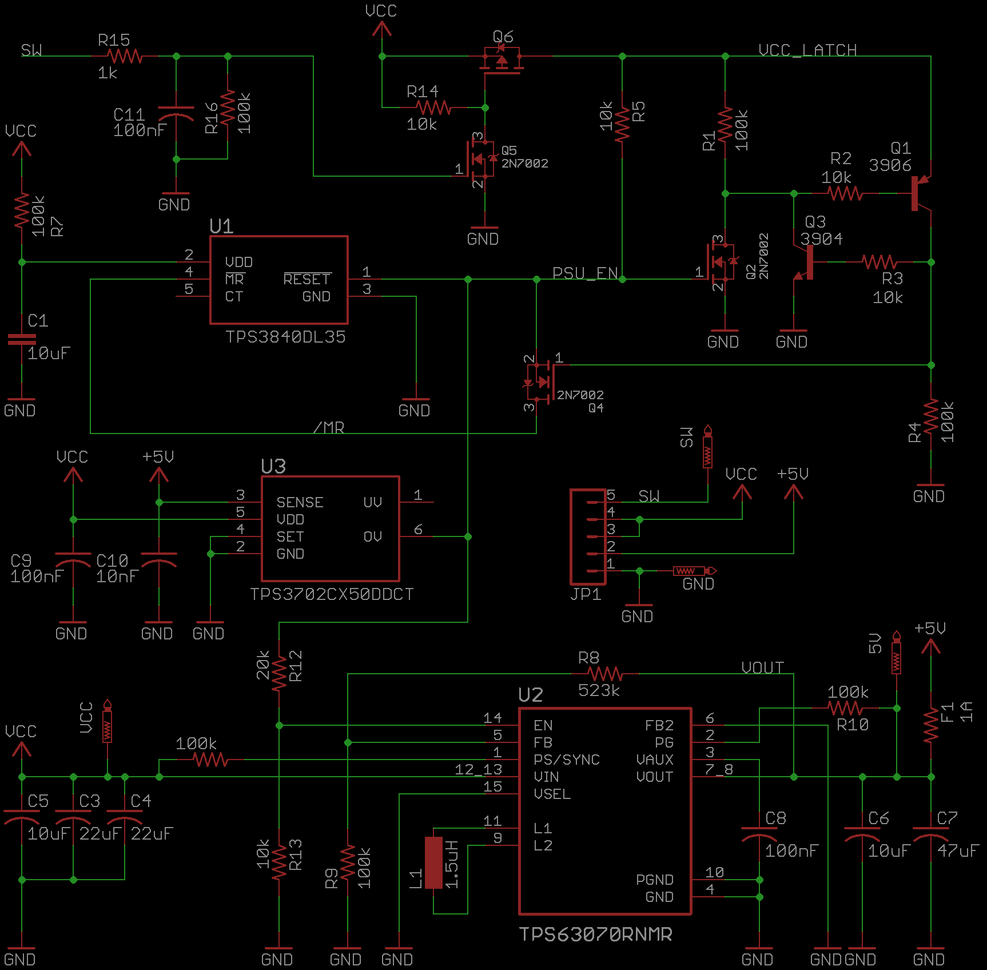
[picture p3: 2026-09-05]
hardware/boards/03-dmgc-pwr-01/Technical/schematic_2-3.png

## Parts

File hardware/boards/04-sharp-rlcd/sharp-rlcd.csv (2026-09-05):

Comment | Designator | Footprint | LCSC
RP2040 | U1 | Package_DFN_QFN:QFN-56-1EP_7x7mm_P0.4mm_EP3.2x3.2mm | C2914104
W25Q16JVSSIQ | U2 | Package_SO:SOIC-8_3.9x4.9mm_P1.27mm | C49987
XC6206P332MR | U3 | Package_TO_SOT_SMD:SOT-23 | C5446
12MHz | X1 | Crystal:Crystal_SMD_3225-4Pin_3.2x2.5mm | C112250
FH34SRJ-10S-0.5SH | J1 | BytendoMods:FFC-SMD_10P-P0.50_FH34SRJ-10S-0.5SH | C324723
686118183522 | J2 | BytendoMods:CON_5051101892_MOL | C262334
USB-C-16P | J3 | Connector_USB:USB_C_Receptacle_HRO_TYPE-C-31-M-12 | C165948
100nF | C1,C2,C3,C4,C5,C6,C7,C8,C9 | Capacitor_SMD:C_0402_1005Metric | C1525
1µF | C10,C11 | Capacitor_SMD:C_0402_1005Metric | C52923
10µF | C12,C13 | Capacitor_SMD:C_0603_1608Metric | C19702
15pF | C14,C15 | Capacitor_SMD:C_0402_1005Metric | C1554
27Ω | R1,R2 | Resistor_SMD:R_0402_1005Metric | C25111
5.1kΩ | R3,R4 | Resistor_SMD:R_0402_1005Metric | C25905
1kΩ | R5 | Resistor_SMD:R_0402_1005Metric | C11702
10kΩ | R6,R7 | Resistor_SMD:R_0402_1005Metric | C25744
SW_PUSH | SW1 | Button_Switch_SMD:SW_SPST_PTS645 | C318884

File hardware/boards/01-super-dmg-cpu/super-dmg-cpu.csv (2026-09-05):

Comment | Designator | Footprint | LCSC
100µf | C1,C23 | Capacitor_Tantalum_SMD:CP_EIA-3528-12_Kemet-T_Pad1.50x2.35mm_HandSolder | C122271
100nF | C10,C24,C25 | Capacitor_SMD:C_0805_2012Metric_Pad1.18x1.45mm_HandSolder | C49678
10nF | C12,C13,C14 | Capacitor_SMD:C_0805_2012Metric_Pad1.18x1.45mm_HandSolder | C1710
100pF | C16,C17,C18,C19 | Capacitor_SMD:C_0805_2012Metric_Pad1.18x1.45mm_HandSolder | C1790
27pF | C21,C22 | Capacitor_SMD:C_0805_2012Metric_Pad1.18x1.45mm_HandSolder | C527182
1µF | C3,C4 | Capacitor_SMD:C_0805_2012Metric_Pad1.18x1.45mm_HandSolder | C28323
10µF | C5,C6 | Capacitor_SMD:C_0805_2012Metric_Pad1.18x1.45mm_HandSolder | C15850
47nF | C7,C8,C9 | Capacitor_SMD:C_0805_2012Metric_Pad1.18x1.45mm_HandSolder | C53134
BATTERY | CN4 | easyeda2kicad:CONN-TH_2P-P1.25_HCTL_HC-1.25-2AW | C2845535
1N414 | D2 | Diode_SMD:D_SOD-123 | C83528
BAV99-7-F | DA1,DA2,DA3,DA4 | kmc_lib:SOT-23-3_L2.9-W1.3-P1.90-LS2.4-BR | C106919
220Ω | R1,R2,R3,R4 | Resistor_SMD:R_0805_2012Metric_Pad1.20x1.40mm_HandSolder | C17557
5.1kΩ | R10,R11 | Resistor_SMD:R_0805_2012Metric_Pad1.20x1.40mm_HandSolder | C27834
510Ω | R5,R6 | Resistor_SMD:R_0805_2012Metric_Pad1.20x1.40mm_HandSolder | C17734
180kΩ | R7 | Resistor_SMD:R_0805_2012Metric_Pad1.20x1.40mm_HandSolder | C17501
1MΩ | R8 | Resistor_SMD:R_0805_2012Metric_Pad1.20x1.40mm_HandSolder | C17514
10kΩ | R9 | Resistor_SMD:R_0805_2012Metric_Pad1.20x1.40mm_HandSolder | C17414
DPDT | SW1 | kmc_lib:DMGB_POWER_SWITCH | C2848866
LPW5209B5F-21 | U5 | easyeda2kicad:SOT-23-5_L2.9-W1.6-P0.95-LS2.8-BL | C517266
CHARGE_PORT | USB1 | kmc_lib:USB_C_16p | C319148
4.194304 MHz | X1 | dmg_lib:HC-49S | C2149317

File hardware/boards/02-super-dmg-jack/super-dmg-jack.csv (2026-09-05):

Comment | Designator | Footprint | LCSC
1µf | C1,C2,C5 | Capacitor_SMD:C_0805_2012Metric_Pad1.18x1.45mm_HandSolder
220pf | C3,C4 | Capacitor_SMD:C_0805_2012Metric_Pad1.18x1.45mm_HandSolder
PJ-3043-B | CN1 | easyeda2kicad:AUDIO-TH_PJ-3043-B | C2682182
DMGB_AUDIO_HEADER | CN2 | kmc_lib:CONN-TH_5P-P1.25_LONGPADS | C722604
Speaker | CN3 | kmc_lib:CONN-TH_2P-P1.25_HCTL_HC-1.25-2AW_LONGPADS | C722595
FerriteBead_Small | FB1,FB2 | Inductor_SMD:L_0805_2012Metric_Pad1.15x1.40mm_HandSolder
220Ω | R1,R2 | Resistor_SMD:R_0805_2012Metric_Pad1.20x1.40mm_HandSolder
100Ω | R3,R4 | Resistor_SMD:R_0805_2012Metric_Pad1.20x1.40mm_HandSolder
10kΩ | R5 | Resistor_SMD:R_0805_2012Metric_Pad1.20x1.40mm_HandSolder
PAM8302AADCR | U1 | easyeda2kicad:SOP-8_L4.9-W3.9-P1.27-LS6.0-BL | C112137
SN74AHC1G14DBVR | U2 | easyeda2kicad:SOT-23-5_L3.0-W1.7-P0.95-LS2.8-BR | C7469
TC33X-2-103E | VR1 | easyeda2kicad:RES-ADJ-SMD_3P-L3.0-W3.8-P1.75-BR | C719176

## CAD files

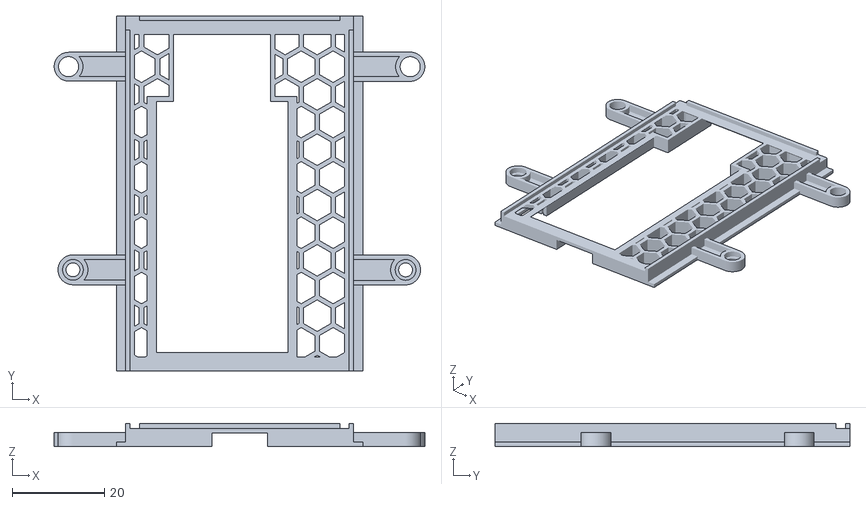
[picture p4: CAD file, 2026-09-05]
hardware/boards/04-sharp-rlcd/bracket/DMG-MIP-BRK-V0.6.stl
80.4 x 77.0 x 5.00

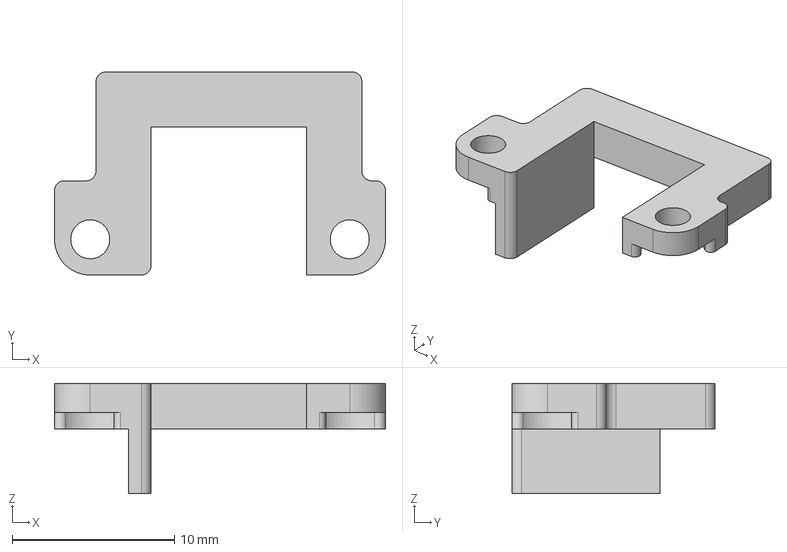
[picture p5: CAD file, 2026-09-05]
hardware/models/super_dmg_jack_spacer.step
20.4 x 12.5 x 6.80 mm

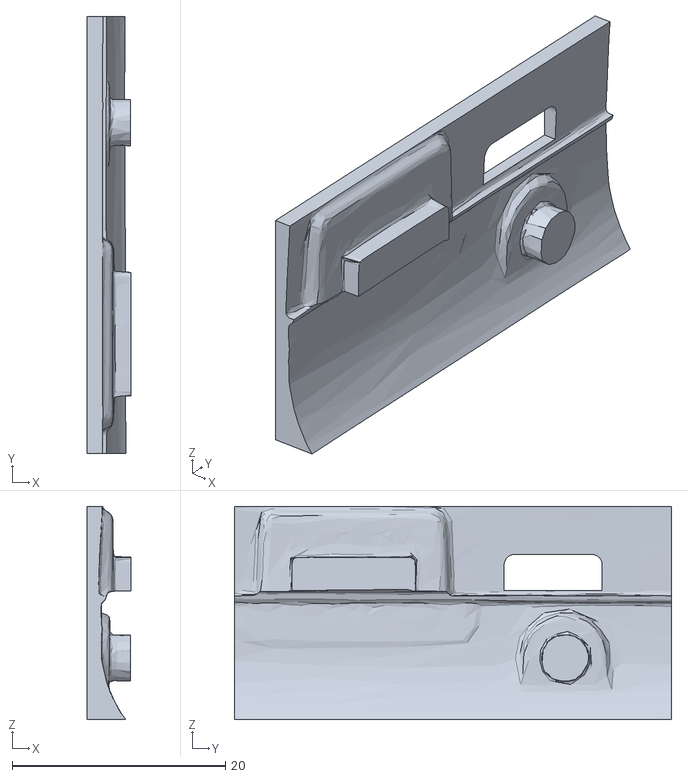
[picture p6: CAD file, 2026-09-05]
hardware/models/dmg_usbc_jig.stl
4.12 x 41.0 x 20.0

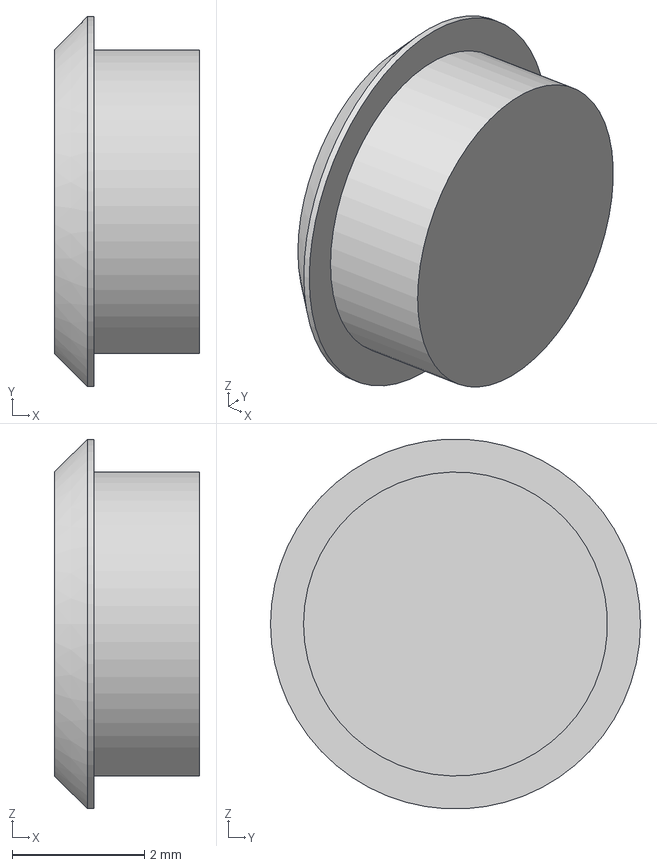
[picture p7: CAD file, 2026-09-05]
hardware/models/dmg_dc_plug.step
2.20 x 5.60 x 5.59 mm

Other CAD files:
hardware/models/dmg_dc_plug.stl
hardware/models/super_dmg_jack_spacer.stl

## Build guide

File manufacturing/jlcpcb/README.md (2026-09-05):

# JLCPCB / JLCONE Manufacturing Guide

This directory contains resources, notes, and configuration specific to manufacturing and assembling DMG-007 boards using **JLCPCB** and the **JLCONE** desktop client (`/Applications/JLCONE.app`).

## Requirements for JLCPCB SMT (PCBA) Assembly

JLCPCB requires three files per board for automated pick-and-place assembly:

1. **Gerber Archive (`gerbers.zip`):** PCB copper, solder mask, silkscreen, edge cuts, and drill files.
2. **BOM (`BOM.csv`):** Maps reference designators to component descriptions, footprints, and **LCSC Part Numbers** (`Cxxxx`).
3. **CPL / Centroid (`CPL.csv`):** Pick-and-place coordinates (`Designator`, `Mid X`, `Mid Y`, `Layer`, `Rotation`).

## Assembly Strategy for DMG-007

* **Maximum Pick-and-Place:** All standard surface-mount passives (resistors, capacitors, inductors, diodes, voltage supervisors, and audio ICs) are mapped to LCSC stock numbers for automated placement.
* **Excluded Parts:**
  * **U1 (SGB-CPU):** Harvested from Japanese Super Game Boy cartridges; hand-soldered after PCBA fabrication.
  * **Through-hole / edge connectors:** Cartridge slot, headphone jack, volume potentiometer, and battery terminals.

## Board Packages

* `super-dmg-cpu/`: Gerbers, BOM, and CPL for the main motherboard.
* `super-dmg-jack/`: Gerbers, BOM, and CPL for the audio amplifier board.
* `dmgc-pwr-01/`: Gerbers, BOM, and CPL for the power regulator board.
* `rlcd-dmg/`: Gerbers, BOM, and CPL for the display controller and debug board.

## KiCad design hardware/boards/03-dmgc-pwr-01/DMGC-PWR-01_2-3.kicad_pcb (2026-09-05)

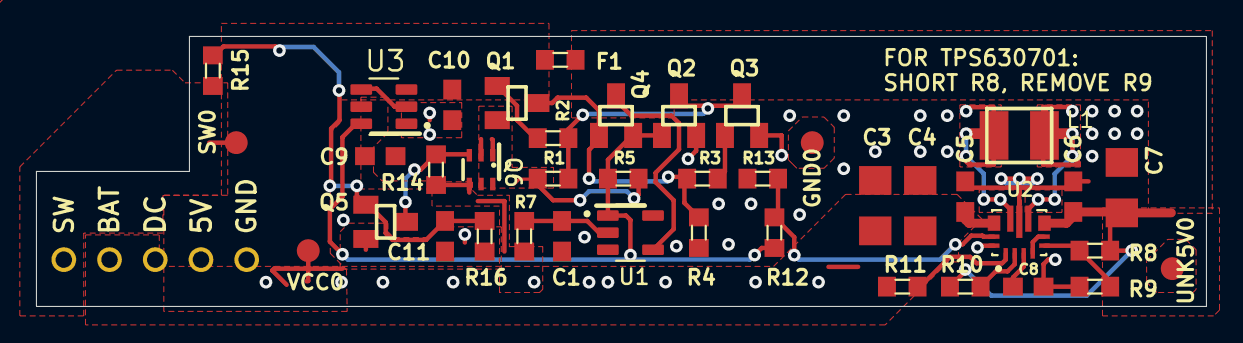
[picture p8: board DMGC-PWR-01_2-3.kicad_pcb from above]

Board: 2 copper layers, 65.0 x 15.0 mm, 41 parts (0 on the bottom side), 22 nets.

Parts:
C1, C5, C6: 10uF; C0603
C3, C4: 22uF; C1206
C7: 47uF; C1206
C8, C9, C11: 100nF; C0603
C10: 10nF; C0603
F1: 1A; R0603
GND0: PTR1B1,27; B1,27
JP1: JP5
L1: 1.5uH; 1212
Q1: MMBT3906LT1SMD; SOT23-BEC
Q2, Q4, Q5: 2N7002; SOT23
Q3: 3904; SOT23-BEC
Q6: SI1401EDH; SOT363_INFINEON
R1, R4, R7, R9, R10, R11, R16: 100k; R0603
R2, R3, R5, R13, R14: 10k; R0603
R8: 523k; R0603
R12: 20k; R0603
R15: 1k; R0603
SW0: PTR1B1,27; B1,27
U1: TPS3840; SOT-23-5
U2: TPS63070RNMR; VREG_TPS63070RNMR
U3: TPS3702; SOT-23-6
UNK5V0: PTR1B1,27; B1,27
VCC0: PTR1B1,27; B1,27

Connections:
+5V: C10.1, F1.1, JP1.2, U3.3
/MR: Q4.3, U1.4
EN: R12.2, R13.1, U2.14
GND: C1.2, C3.2, C4.2, C5.2, C6.2, C7.2, C8.2, C9.2, C10.2, C11.2, GND0.TP, JP1.1, Q2.2, Q3.E, Q5.2, R4.1, R9.1, R13.2, R16.1, U1.3, U2.4, U2.6, U2.10, U2.15, U3.2, U3.4
unnamed: C1.1, R7.1, U1.2
unnamed: L1.2, U2.11
unnamed: L1.1, U2.9
unnamed: R10.2, U2.2
unnamed: C8.1, U2.3
unnamed: R8.1, R9.2, U2.5
unnamed: Q5.3, Q6.3, R14.2
unnamed: C11.1, Q5.1, R15.2, R16.2
unnamed: Q1.B, R2.1
unnamed: Q1.C, Q4.1, R3.1, R4.2
unnamed: Q3.B, R3.2
unnamed: Q2.3, Q3.C, R1.1, R2.2
PS: R11.1, U2.1
PSU_EN: Q2.1, Q4.2, R5.2, R12.1, U1.1, U3.6
SW: JP1.5, R15.1, SW0.TP
VCC: C3.1, C4.1, C5.1, C9.1, JP1.3, JP1.4, Q6.4, R7.2, R11.2, R14.1, U2.12_13, U3.5, VCC0.TP
VCC_LATCH: Q1.E, Q6.1, Q6.2, Q6.5, Q6.6, R1.2, R5.1
VOUT: C6.1, C7.1, F1.2, R8.2, R10.1, U2.7_8, UNK5V0.TP

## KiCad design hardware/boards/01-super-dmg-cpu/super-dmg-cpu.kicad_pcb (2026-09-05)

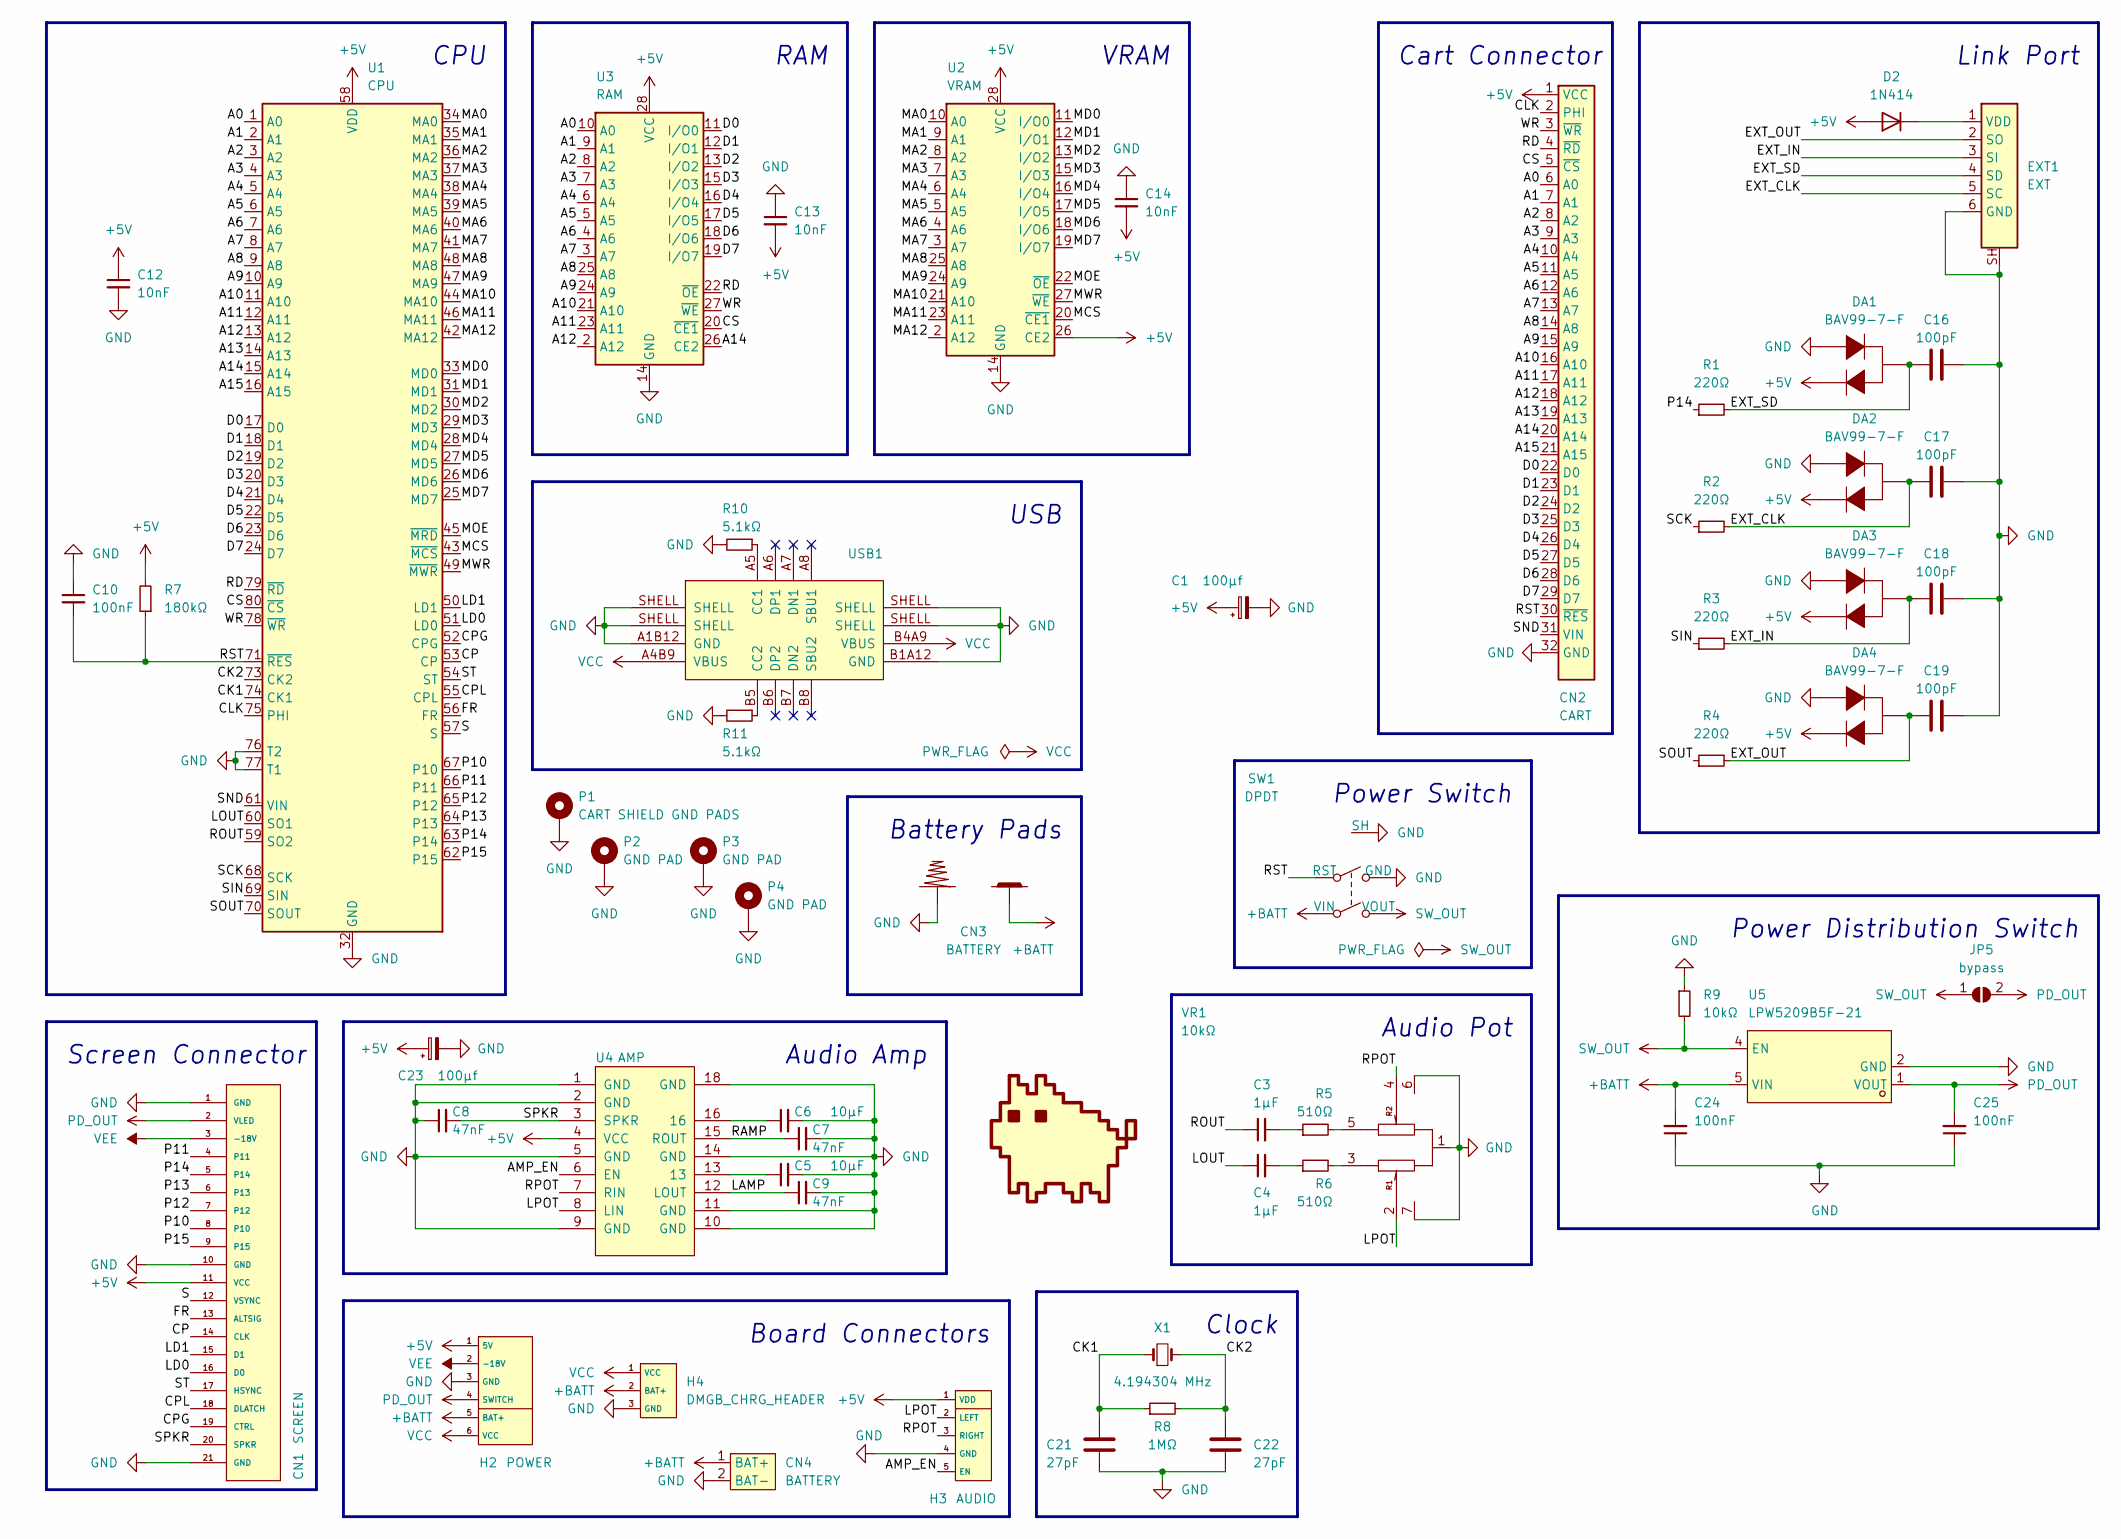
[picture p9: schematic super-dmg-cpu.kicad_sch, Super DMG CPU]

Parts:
C1, C23: 100µf; CP_EIA-3528-12_Kemet-T_Pad1.50x2.35mm_HandSolder; LCSC C122271
C3, C4: 1µF; C_0805_2012Metric_Pad1.18x1.45mm_HandSolder; LCSC C28323
C5, C6: 10µF; C_0805_2012Metric_Pad1.18x1.45mm_HandSolder; LCSC C15850
C7, C8, C9: 47nF; C_0805_2012Metric_Pad1.18x1.45mm_HandSolder; LCSC C53134
C10, C24, C25: 100nF; C_0805_2012Metric_Pad1.18x1.45mm_HandSolder; LCSC C49678
C12, C13, C14: 10nF; C_0805_2012Metric_Pad1.18x1.45mm_HandSolder; LCSC C1710
C16, C17, C18, C19: 100pF; C_0805_2012Metric_Pad1.18x1.45mm_HandSolder; LCSC C1790
C21, C22: 27pF; C_0805_2012Metric_Pad1.18x1.45mm_HandSolder; LCSC C527182
CN1: SCREEN; DMG_FPC_CONN
CN2: CART; DMG_CART_CONN
CN3: BATTERY; DMG_BATTERY_PADS
CN4: BATTERY; CONN-TH_2P-P1.25_HCTL_HC-1.25-2AW; LCSC C2845535
D2: 1N414; D_SOD-123; LCSC C83528
DA1, DA2, DA3, DA4: BAV99-7-F; SOT-23-3_L2.9-W1.3-P1.90-LS2.4-BR; LCSC C106919
EXT1: EXT; DMG_LINK_CONN
G1: kmc; kmc_6mm
H2: POWER; PAD_2.54_HYBRID_X6
H3: AUDIO; PAD_2.54_HYBRID_X5
H4: DMGB_CHRG_HEADER; PAD_2.54_HYBRID_X3
JP5: bypass; solder_jumper_x2
P1: CART SHIELD GND PADS; DMG_CART_SHIELD_CONTACT
P2, P3, P4: GND PAD; DMG_GROUNDPAD
R1, R2, R3, R4: 220Ω; R_0805_2012Metric_Pad1.20x1.40mm_HandSolder; LCSC C17557
R5, R6: 510Ω; R_0805_2012Metric_Pad1.20x1.40mm_HandSolder; LCSC C17734
R7: 180kΩ; R_0805_2012Metric_Pad1.20x1.40mm_HandSolder; LCSC C17501
R8: 1MΩ; R_0805_2012Metric_Pad1.20x1.40mm_HandSolder; LCSC C17514
R9: 10kΩ; R_0805_2012Metric_Pad1.20x1.40mm_HandSolder; LCSC C17414
R10, R11: 5.1kΩ; R_0805_2012Metric_Pad1.20x1.40mm_HandSolder; LCSC C27834
SW1: DPDT; DMGB_POWER_SWITCH; LCSC C2848866
U1: CPU; DMG_CPU
U2: VRAM; DMG_RAM_64K
U3: RAM; DMG_RAM_64K
U4: AMP; DMG_AMP
U5: LPW5209B5F-21; SOT-23-5_L2.9-W1.6-P0.95-LS2.8-BL; JLC Part Extended Part
USB1: CHARGE_PORT; USB_C_16p; LCSC C319148
VR1: 10kΩ; DMG_VOLUME_POT
X1: 4.194304 MHz; HC-49S; LCSC C2149317

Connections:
+5V: C1.1, C12.1, C13.2, C14.2, C23.1, CN1.11 (VCC), CN2.1 (VCC), D2.2 (A), DA1.2 (K), DA2.2 (K), DA3.2 (K), DA4.2 (K), H2.1 (5V), H3.1 (VDD), R7.2, U1.58 (VDD), U2.26 (CE2), U2.28 (VCC), U3.28 (VCC), U4.4 (VCC)
+BATT: C24.2, CN3.1 (+), CN4.1 (BAT+), H2.5 (BAT+), H4.2 (BAT+), SW1.2 (VIN), U5.5 (VIN)
/A0: CN2.6 (A0), U1.1 (A0), U3.10 (A0)
/A1: CN2.7 (A1), U1.2 (A1), U3.9 (A1)
/A2: CN2.8 (A2), U1.3 (A2), U3.8 (A2)
/A3: CN2.9 (A3), U1.4 (A3), U3.7 (A3)
/A4: CN2.10 (A4), U1.5 (A4), U3.6 (A4)
/A5: CN2.11 (A5), U1.6 (A5), U3.5 (A5)
/A6: CN2.12 (A6), U1.7 (A6), U3.4 (A6)
/A7: CN2.13 (A7), U1.8 (A7), U3.3 (A7)
/A8: CN2.14 (A8), U1.9 (A8), U3.25 (A8)
/A9: CN2.15 (A9), U1.10 (A9), U3.24 (A9)
/A10: CN2.16 (A10), U1.11 (A10), U3.21 (A10)
/A11: CN2.17 (A11), U1.12 (A11), U3.23 (A11)
/A12: CN2.18 (A12), U1.13 (A12), U3.2 (A12)
/A13: CN2.19 (A13), U1.14 (A13)
/A14: CN2.20 (A14), U1.15 (A14), U3.26 (CE2)
/A15: CN2.21 (A15), U1.16 (A15)
/AMP_EN: H3.5 (EN), U4.6 (EN)
/CK1: C21.2, R8.1, U1.74 (CK1), X1.1
/CK2: C22.2, R8.2, U1.73 (CK2), X1.2
/CLK: CN2.2 (PHI), U1.75 (PHI)
/CP: CN1.14 (CLK), U1.53 (CP)
/CPG: CN1.19 (CTRL), U1.52 (CPG)
/CPL: CN1.18 (DLATCH), U1.55 (CPL)
/CS: CN2.5 (~CS), U1.80 (~CS), U3.20 (~CE1)
/D0: CN2.22 (D0), U1.17 (D0), U3.11 (I/O0)
/D1: CN2.23 (D1), U1.18 (D1), U3.12 (I/O1)
/D2: CN2.24 (D2), U1.19 (D2), U3.13 (I/O2)
/D3: CN2.25 (D3), U1.20 (D3), U3.15 (I/O3)
/D4: CN2.26 (D4), U1.21 (D4), U3.16 (I/O4)
/D5: CN2.27 (D5), U1.22 (D5), U3.17 (I/O5)
/D6: CN2.28 (D6), U1.23 (D6), U3.18 (I/O6)
/D7: CN2.29 (D7), U1.24 (D7), U3.19 (I/O7)
/EXT_CLK: C17.1, DA2.3 (K), EXT1.5 (SC), R2.2
/EXT_IN: C18.1, DA3.3 (K), EXT1.3 (SI), R3.2
/EXT_OUT: C19.1, DA4.3 (K), EXT1.2 (SO), R4.2
/EXT_SD: C16.1, DA1.3 (K), EXT1.4 (SD), R1.2
/FR: CN1.13 (ALTSIG), U1.56 (FR)
/LAMP: C9.1, U4.12 (LOUT)
/LD0: CN1.16 (D0), U1.51 (LD0)
/LD1: CN1.15 (D1), U1.50 (LD1)
/LOUT: C4.1, U1.60 (SO1)
/LPOT: H3.2 (LEFT), U4.8 (LIN), VR1.2
/MA0: U1.34 (MA0), U2.10 (A0)
/MA1: U1.35 (MA1), U2.9 (A1)
/MA2: U1.36 (MA2), U2.8 (A2)
/MA3: U1.37 (MA3), U2.7 (A3)
/MA4: U1.38 (MA4), U2.6 (A4)
/MA5: U1.39 (MA5), U2.5 (A5)
/MA6: U1.40 (MA6), U2.4 (A6)
/MA7: U1.41 (MA7), U2.3 (A7)
/MA8: U1.48 (MA8), U2.25 (A8)
/MA9: U1.47 (MA9), U2.24 (A9)
/MA10: U1.44 (MA10), U2.21 (A10)
/MA11: U1.46 (MA11), U2.23 (A11)
/MA12: U1.42 (MA12), U2.2 (A12)
/MCS: U1.43 (~MCS), U2.20 (~CE1)
/MD0: U1.33 (MD0), U2.11 (I/O0)
/MD1: U1.31 (MD1), U2.12 (I/O1)
/MD2: U1.30 (MD2), U2.13 (I/O2)
/MD3: U1.29 (MD3), U2.15 (I/O3)
/MD4: U1.28 (MD4), U2.16 (I/O4)
/MD5: U1.27 (MD5), U2.17 (I/O5)
/MD6: U1.26 (MD6), U2.18 (I/O6)
/MD7: U1.25 (MD7), U2.19 (I/O7)
/MOE: U1.45 (~MRD), U2.22 (~OE)
/MWR: U1.49 (~MWR), U2.27 (~WE)
/P10: CN1.8 (P10), U1.67 (P10)
/P11: CN1.4 (P11), U1.66 (P11)
/P12: CN1.7 (P12), U1.65 (P12)
/P13: CN1.6 (P13), U1.64 (P13)
/P14: CN1.5 (P14), R1.1, U1.63 (P14)
/P15: CN1.9 (P15), U1.62 (P15)
/RAMP: C7.1, U4.15 (ROUT)
/RD: CN2.4 (~RD), U1.79 (~RD), U3.22 (~OE)
/ROUT: C3.1, U1.59 (SO2)
/RPOT: H3.3 (RIGHT), U4.7 (RIN), VR1.4
/RST: C10.2, CN2.30 (~RES), R7.1, SW1.5 (RST), U1.71 (~RES)
/S: CN1.12 (VSYNC), U1.57 (S)
/SCK: R2.1, U1.68 (SCK)
/SIN: R3.1, U1.69 (SIN)
/SND: CN2.31 (VIN), U1.61 (VIN)
/SOUT: R4.1, U1.70 (SOUT)
/SPKR: C8.2, CN1.20 (SPKR), U4.3 (SPKR)
/ST: CN1.17 (HSYNC), U1.54 (ST)
/WR: CN2.3 (~WR), U1.78 (~WR), U3.27 (~WE)
GND: C1.2, C5.2, C6.2, C7.2, C8.1, C9.2, C10.1, C12.2, C13.1, C14.1, C16.2, C17.2, C18.2, C19.2, C21.1, C22.1, C23.2, C24.1, C25.1, CN1.1 (GND), CN1.10 (GND), CN1.21 (GND), CN2.32 (GND), CN3.2 (-), CN4.2 (BAT-), DA1.1 (A), DA2.1 (A), DA3.1 (A), DA4.1 (A), EXT1.6 (GND), EXT1.SH, H2.3 (GND), H3.4 (GND), H4.3 (GND), P1.1, P2.1, P3.1, P4.1, R9.1, R10.2, R11.2, SW1.6 (GND), SW1.7 (SH), U1.32 (GND), U1.72 (GND), U1.76 (T2), U1.77 (T1), U2.14 (GND), U3.14 (GND), U4.1 (GND), U4.2 (GND), U4.5 (GND), U4.9 (GND), U4.10 (GND), U4.11 (GND), U4.14 (GND), U4.18 (GND), U5.2 (GND), USB1.A1B12 (GND), USB1.B1A12 (GND), USB1.SHELL, VR1.1, VR1.6 (EH), VR1.7 (EH)
unnamed: C3.2, R5.1
unnamed: C4.2, R6.1
unnamed: C5.1, U4.13
unnamed: C6.1, U4.16
unnamed: D2.1 (K), EXT1.1 (VDD)
unnamed: R5.2, VR1.5
unnamed: R6.2, VR1.3
unnamed: R10.1, USB1.A5 (CC1)
unnamed: R11.1, USB1.B5 (CC2)
PD_OUT: C25.2, CN1.2 (VLED), H2.4 (SWITCH), JP5.2 (B), U5.1 (VOUT)
SW_OUT: JP5.1 (A), R9.2, SW1.1 (VOUT), U5.4 (EN)
VCC: H2.6 (VCC), H4.1 (VCC), USB1.A4B9 (VBUS), USB1.B4A9 (VBUS)
VEE: CN1.3 (-18V), H2.2 (-18V)

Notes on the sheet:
USB
VRAM
Clock
Board Connectors
Power Switch
Battery Pads
Audio Amp
Link Port
Cart Connector
RAM
CPU
Audio Pot
Power Distribution Switch
Screen Connector

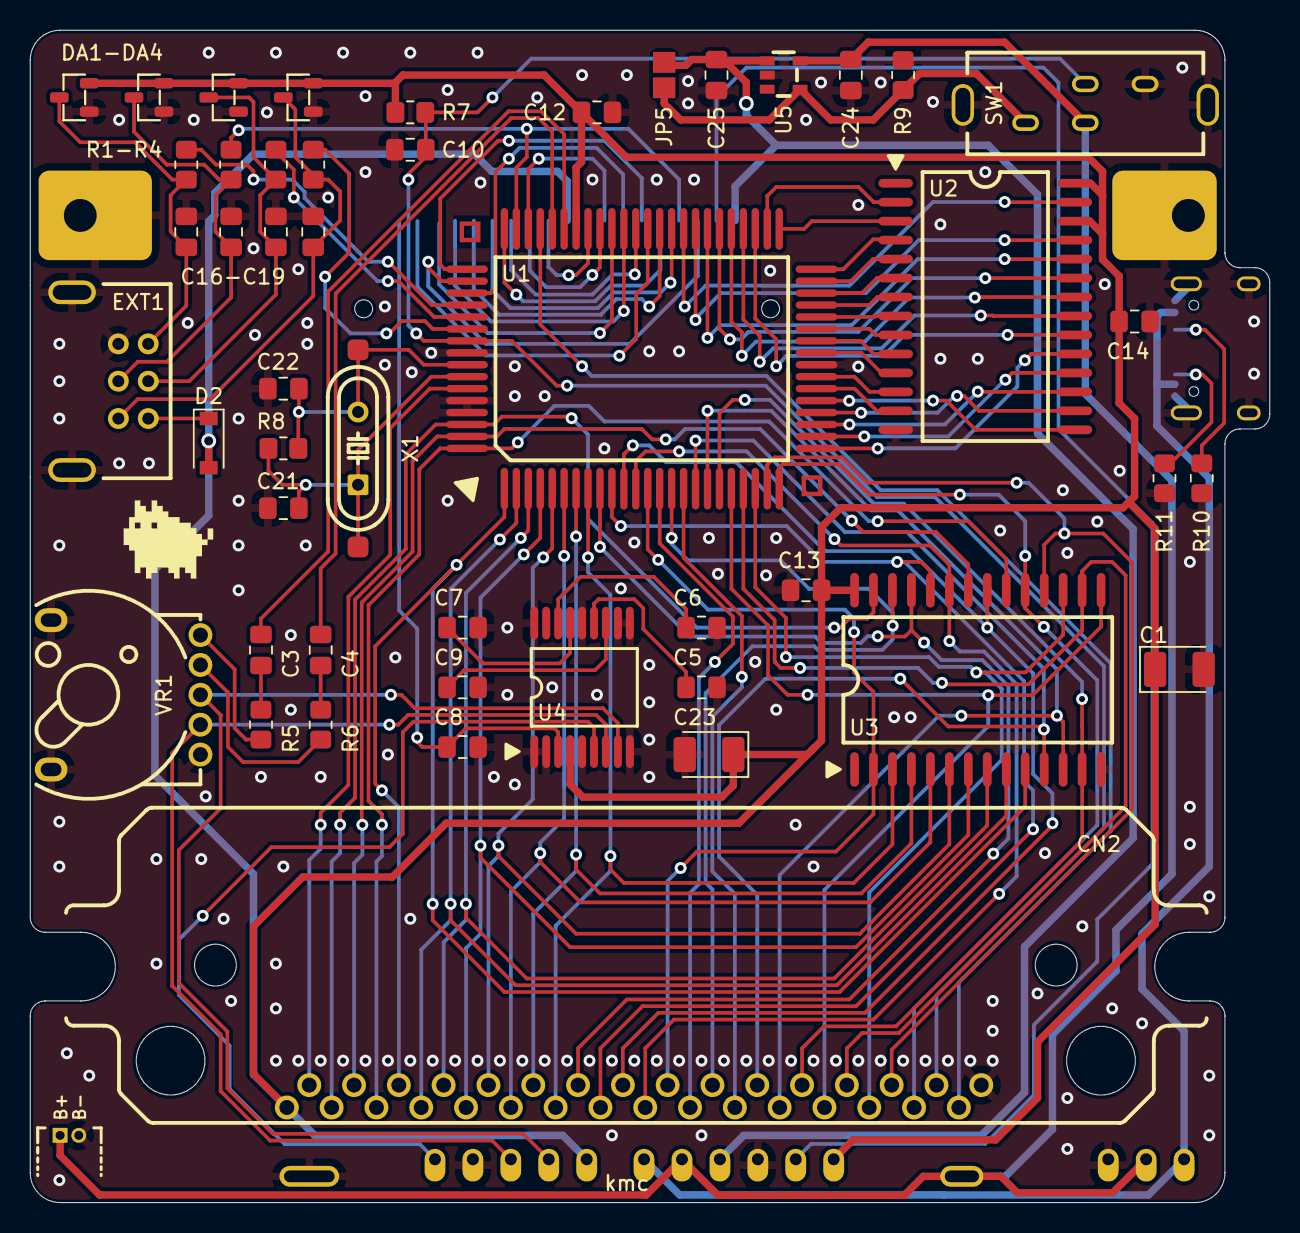
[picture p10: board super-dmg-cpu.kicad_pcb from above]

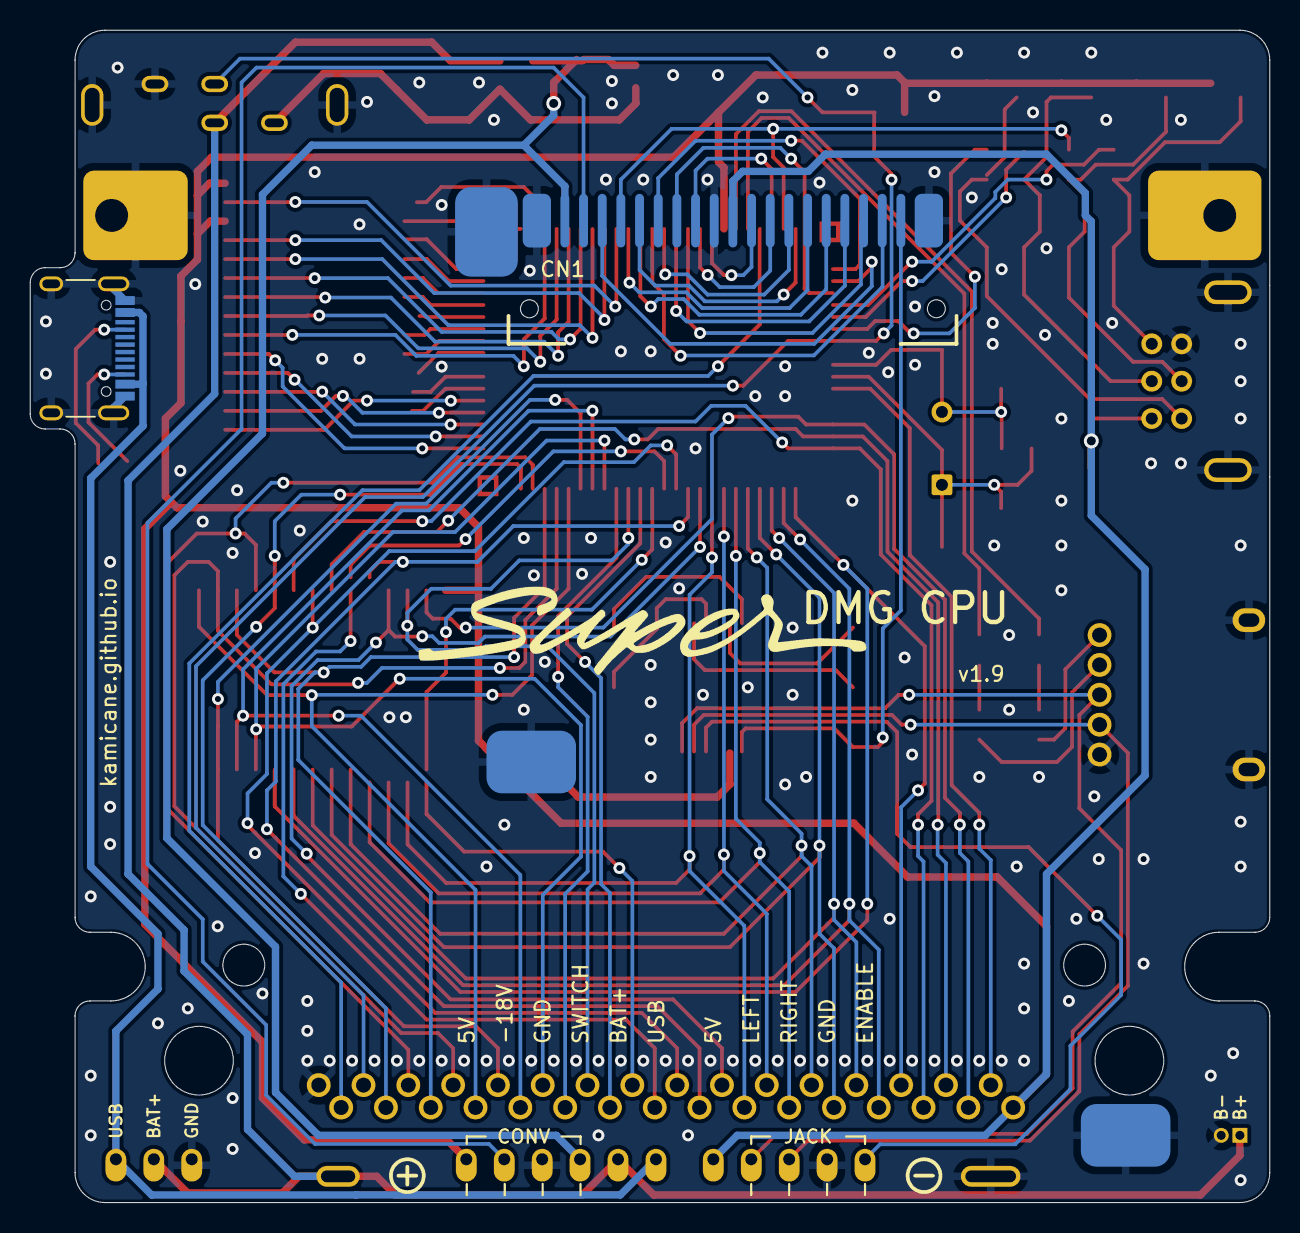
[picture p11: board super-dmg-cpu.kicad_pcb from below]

Board: 2 copper layers, 83.0 x 78.5 mm, 60 parts (8 on the bottom side), 101 nets.

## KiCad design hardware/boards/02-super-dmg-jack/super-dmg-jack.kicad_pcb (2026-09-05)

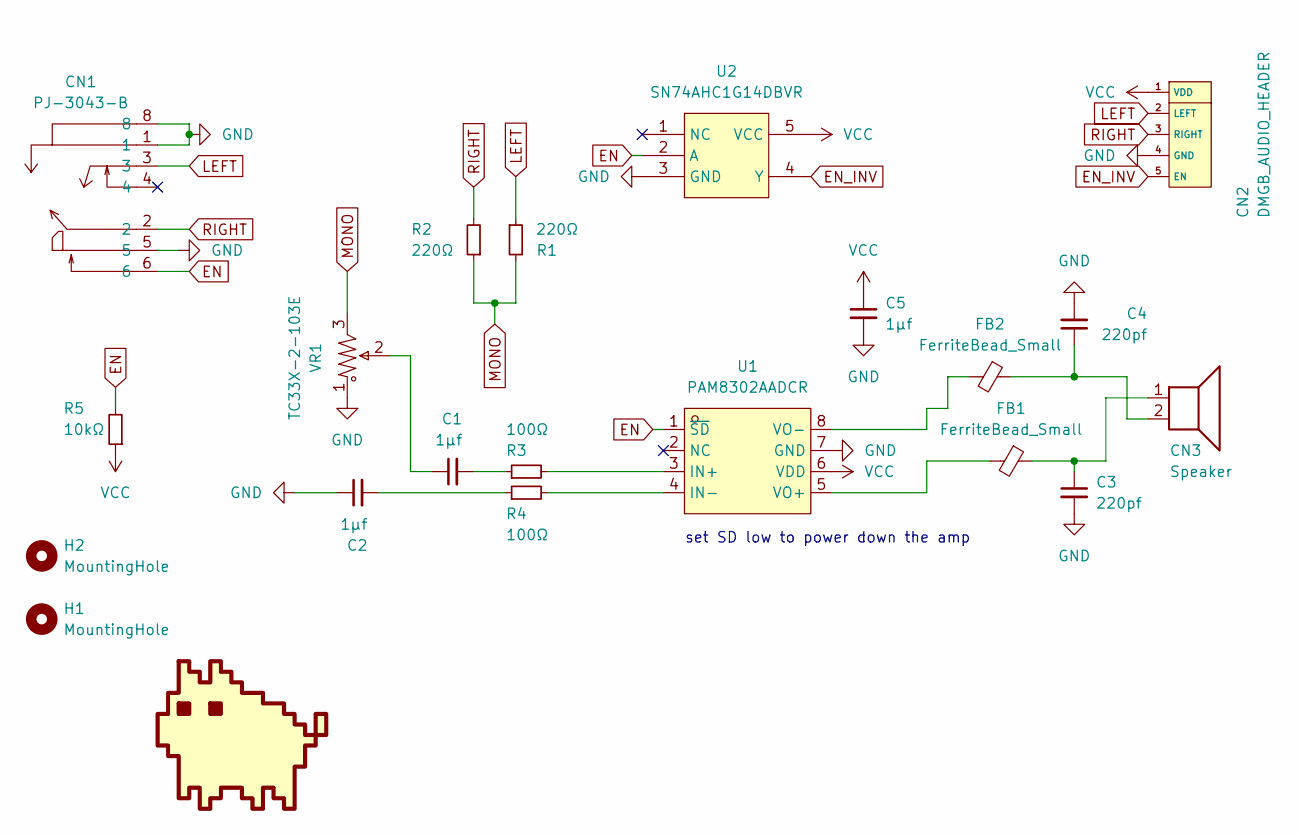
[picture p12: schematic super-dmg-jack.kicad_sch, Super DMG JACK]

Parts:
C1, C2, C5: 1µf; C_0805_2012Metric_Pad1.18x1.45mm_HandSolder
C3, C4: 220pf; C_0805_2012Metric_Pad1.18x1.45mm_HandSolder
CN1: PJ-3043-B; AUDIO-TH_PJ-3043-B; LCSC C2682182
CN2: DMGB_AUDIO_HEADER; CONN-TH_5P-P1.25_LONGPADS; LCSC C722604
CN3: Speaker; CONN-TH_2P-P1.25_HCTL_HC-1.25-2AW_LONGPADS; LCSC C722595
FB1, FB2: FerriteBead_Small; L_0805_2012Metric_Pad1.15x1.40mm_HandSolder
G1: kmc
H1, H2: MountingHole; MountingHole_2.2mm_M2
R1, R2: 220Ω; R_0805_2012Metric_Pad1.20x1.40mm_HandSolder
R3, R4: 100Ω; R_0805_2012Metric_Pad1.20x1.40mm_HandSolder
R5: 10kΩ; R_0805_2012Metric_Pad1.20x1.40mm_HandSolder
U1: PAM8302AADCR; SOP-8_L4.9-W3.9-P1.27-LS6.0-BL; LCSC C112137
U2: SN74AHC1G14DBVR; SOT-23-5_L3.0-W1.7-P0.95-LS2.8-BR; LCSC C7469
VR1: TC33X-2-103E; RES-ADJ-SMD_3P-L3.0-W3.8-P1.75-BR; LCSC C719176

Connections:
EN: CN1.6, R5.2, U1.1 (~SD), U2.2 (A)
EN_INV: CN2.5 (EN), U2.4 (Y)
GND: C2.1, C3.2, C4.2, C5.2, CN1.1, CN1.5, CN1.8, CN2.4 (GND), U1.7 (GND), U2.3 (GND), VR1.1
LEFT: CN1.3, CN2.2 (LEFT), R1.1
MONO: R1.2, R2.1, VR1.3
unnamed: C1.1, VR1.2
unnamed: C1.2, R3.1
unnamed: C2.2, R4.1
unnamed: C3.1, CN3.1, FB1.1
unnamed: C4.1, CN3.2, FB2.1
unnamed: FB1.2, U1.5 (VO+)
unnamed: FB2.2, U1.8 (VO-)
unnamed: R3.2, U1.3 (IN+)
unnamed: R4.2, U1.4 (IN-)
RIGHT: CN1.2, CN2.3 (RIGHT), R2.2
VCC: C5.1, CN2.1 (VDD), R5.1, U1.6 (VDD), U2.5 (VCC)

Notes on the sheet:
set SD low to power down the amp

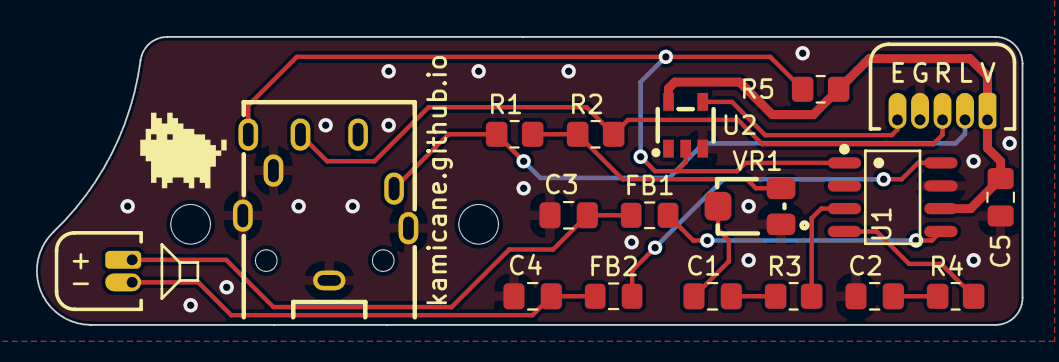
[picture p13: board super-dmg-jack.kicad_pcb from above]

Board: 2 copper layers, 54.8 x 16.0 mm, 21 parts (0 on the bottom side), 16 nets.

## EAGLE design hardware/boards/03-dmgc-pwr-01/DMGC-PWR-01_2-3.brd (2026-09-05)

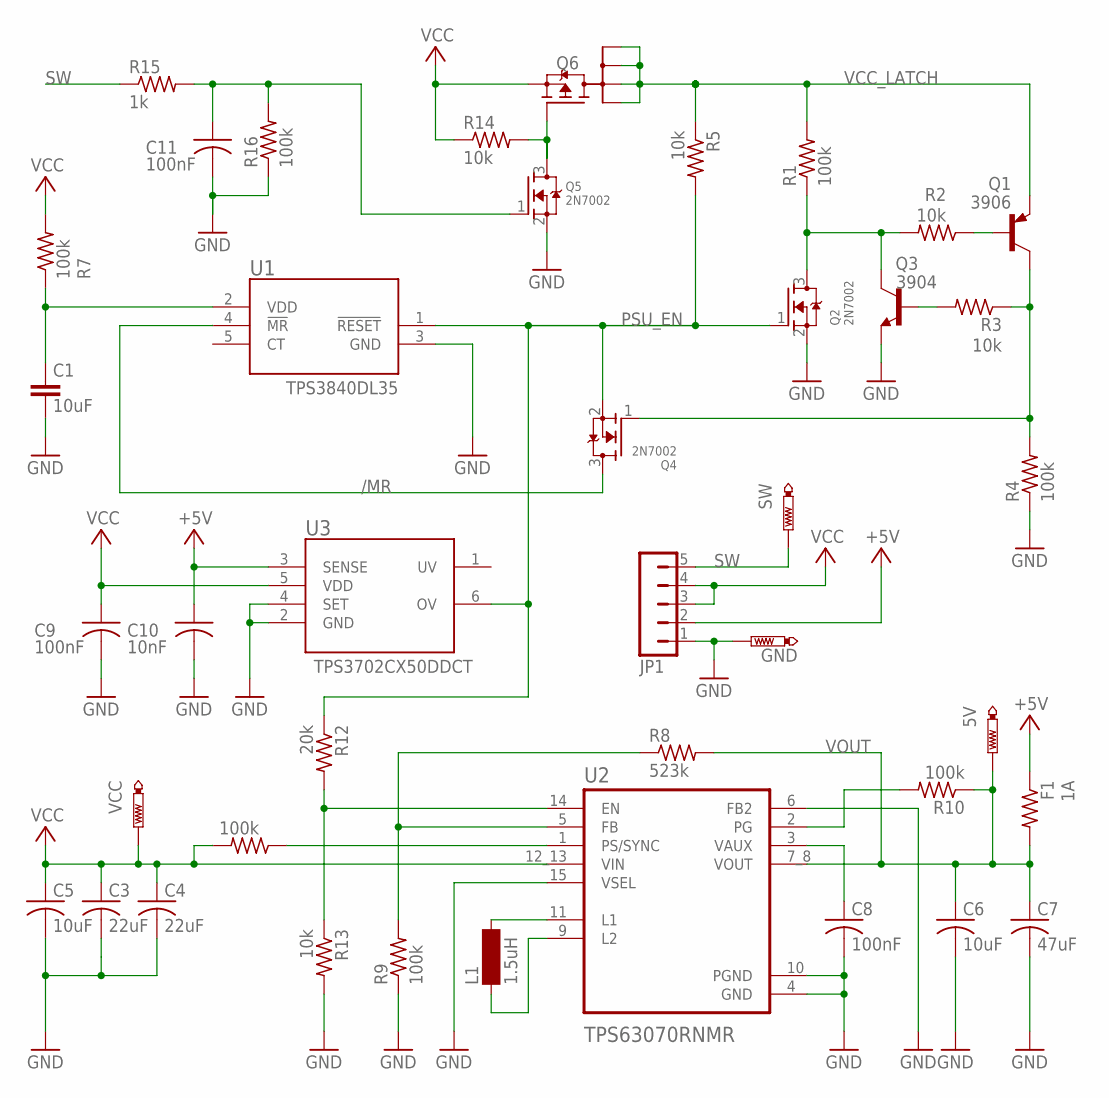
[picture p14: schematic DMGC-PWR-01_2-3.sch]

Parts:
5V: PTR1B1,27; B1,27
C1, C5, C6: 10uF; C0603
C3, C4: 22uF; C1206
C7: 47uF; C1206
C8, C9, C11: 100nF; C0603
C10: 10nF; C0603
F1: 1A; R0603
GND: PTR1B1,27; B1,27
JP1: JP5
L1: 1.5uH; 1212
Q1: MMBT3906LT1SMD; SOT23-BEC
Q2, Q4, Q5: 2N7002; SOT23
Q3: 3904; SOT23-BEC
Q6: SI1401EDH; SOT363_INFINEON
R1, R4, R7, R9, R10, R11, R16: 100k; R0603
R2, R3, R5, R13, R14: 10k; R0603
R8: 523k; R0603
R12: 20k; R0603
R15: 1k; R0603
SW: PTR1B1,27; B1,27
U1: TPS3840; SOT-23-5
U2: TPS63070RNMR; VREG_TPS63070RNMR
U3: TPS3702; SOT-23-6
VCC: PTR1B1,27; B1,27

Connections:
+5V: C10.1, F1.1, JP1.2, U3.3 (SENSE)
/MR: Q4.3 (D), U1.4 (!MR)
EN: R12.2, R13.1, U2.14 (EN)
GND: C1.2, C3.2, C4.2, C5.2, C6.2, C7.2, C8.2, C9.2, C10.2, C11.2, GND.TP, JP1.1, Q2.2 (S), Q3.E, Q5.2 (S), R4.1, R9.1, R13.2, R16.1, U1.3 (GND), U2.4 (GND), U2.6 (FB2), U2.10 (PGND), U2.15 (VSEL), U3.2 (GND), U3.4 (SET)
unnamed: C1.1, R7.1, U1.2 (VDD)
unnamed: L1.2, U2.11 (L1)
unnamed: L1.1, U2.9 (L2)
unnamed: R10.2, U2.2 (PG)
unnamed: C8.1, U2.3 (VAUX)
unnamed: R8.1, R9.2, U2.5 (FB)
unnamed: Q5.3 (D), Q6.3 (G), R14.2
unnamed: C11.1, Q5.1 (G), R15.2, R16.2
unnamed: Q1.B, R2.1
unnamed: Q1.C, Q4.1 (G), R3.1, R4.2
unnamed: Q3.B, R3.2
unnamed: Q2.3 (D), Q3.C, R1.1, R2.2
PS: R11.1, U2.1 (PS/SYNC)
PSU_EN: Q2.1 (G), Q4.2 (S), R5.2, R12.1, U1.1 (!RESET), U3.6 (OV)
SW: JP1.5, R15.1, SW.TP
VCC: C3.1, C4.1, C5.1, C9.1, JP1.3, JP1.4, Q6.4 (S), R7.2, R11.2, R14.1, U2.12_13 (VIN), U3.5 (VDD), VCC.TP
VCC_LATCH: Q1.E, Q6.1 (D1), Q6.2 (D2), Q6.5 (D5), Q6.6 (D6), R1.2, R5.1
VOUT: 5V.TP, C6.1, C7.1, F1.2, R8.2, R10.1, U2.7_8 (VOUT)

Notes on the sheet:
3906
TPS3840DL35
TPS3702CX50DDCT

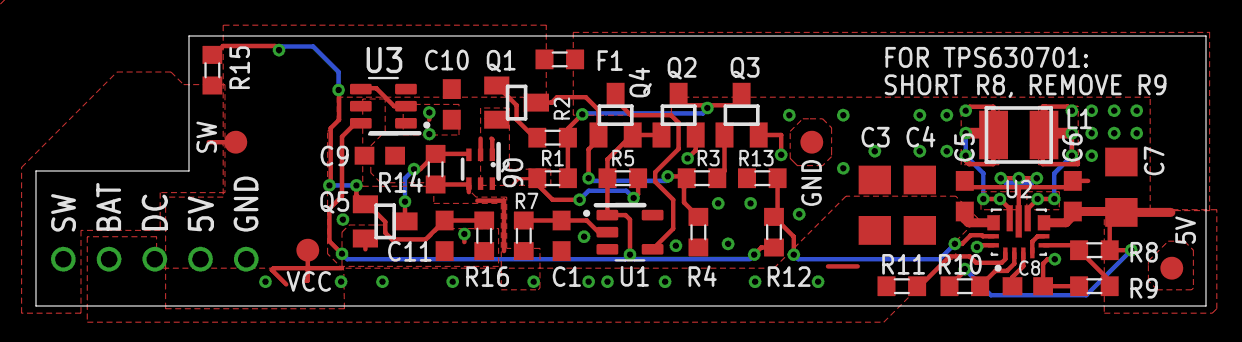
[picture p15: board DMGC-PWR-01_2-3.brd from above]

Board: 2 copper layers, 65.0 x 15.0 mm, 41 parts (0 on the bottom side), 22 nets.

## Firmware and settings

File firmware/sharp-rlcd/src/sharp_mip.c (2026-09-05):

#include <stdio.h>
#include <string.h>
#include "pico/stdlib.h"
#include "hardware/spi.h"
#include "hardware/dma.h"

/*
 * Sharp LS032B7DD02 Memory LCD Driver
 * Resolution: 336 x 536 (Active viewing area scaled 2x: 320 x 288)
 */

#define SHARP_SPI_PORT   spi0
#define PIN_SHARP_CS     17
#define PIN_SHARP_CLK    18
#define PIN_SHARP_MOSI   19
#define PIN_SHARP_DISP   20

#define SHARP_WIDTH      336
#define SHARP_HEIGHT     536

// Command Mode flags
#define SHARP_CMD_UPDATE 0x01
#define SHARP_CMD_VCOM   0x02
#define SHARP_CMD_CLEAR  0x04

static uint8_t vcom_state = 0;

void sharp_mip_init(void) {
    spi_init(SHARP_SPI_PORT, 2000000); // 2 MHz SPI clock
    gpio_set_function(PIN_SHARP_CLK, GPIO_FUNC_SPI);
    gpio_set_function(PIN_SHARP_MOSI, GPIO_FUNC_SPI);
    
    gpio_init(PIN_SHARP_CS);
    gpio_set_dir(PIN_SHARP_CS, GPIO_OUT);
    gpio_put(PIN_SHARP_CS, 0);
    
    gpio_init(PIN_SHARP_DISP);
    gpio_set_dir(PIN_SHARP_DISP, GPIO_OUT);
    gpio_put(PIN_SHARP_DISP, 1); // Turn on display
}

void sharp_mip_toggle_vcom(void) {
    vcom_state ^= SHARP_CMD_VCOM;
}

// 2x2 Bayer Dither Matrix for 4 shades of Game Boy grayscale:
// 0 (Black), 1 (Dark Gray), 2 (Light Gray), 3 (White)
static const uint8_t bayer_2x2[4][2] = {
    // Row 0, Row 1 (2 bits wide per row: bit 0, bit 1)
    { 0b00, 0b00 }, // Level 0 (Black): 0 pixels lit
    { 0b10, 0b00 }, // Level 1 (Dark Gray): 1 pixel lit
    { 0b10, 0b01 }, // Level 2 (Light Gray): 2 pixels lit
    { 0b11, 0b11 }  // Level 3 (White): all 4 pixels lit
};

void sharp_render_line(uint16_t gb_y, const uint8_t *gb_line_2bit, uint8_t *out_row0, uint8_t *out_row1) {
    // Expands 160 2-bit pixels to 320 1-bit pixels across two scanlines
    for (int x = 0; x < 160; x++) {
        uint8_t pixel_val = (gb_line_2bit[x / 4] >> ((x % 4) * 2)) & 0x03;
        uint8_t r0 = bayer_2x2[pixel_val][0];
        uint8_t r1 = bayer_2x2[pixel_val][1];
        
        int byte_idx = (x * 2) / 8;
        int bit_shift = (x * 2) % 8;
        
        out_row0[byte_idx] |= (r0 << bit_shift);
        out_row1[byte_idx] |= (r1 << bit_shift);
    }
}

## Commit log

2026-09-05 Initialize DMG-007 multi-board workspace, vendor docs, and hardware modules
    [DMG-MIP-BRK-V0.6.stl, DMGC-PWR-01_2-3.brd, DMGC-PWR-01_2-3.sch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]
2026-09-05 Update display subsystem to clean-room Sharp RLCD driver and VRAM bus
    [DMG-MIP-BRK-V0.6.stl, DMGC-PWR-01_2-3.kicad_pcb, sharp-rlcd.csv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]
